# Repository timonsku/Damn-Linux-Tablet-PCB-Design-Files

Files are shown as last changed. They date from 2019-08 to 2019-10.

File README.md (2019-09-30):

DLT - A Damn Linux Tablet
==========
PCB Design Files
-----
Collection of PCB and CAD design files for DLT ( https://hackaday.io/project/164845-dlt-one-a-damn-linux-tablet ).
This project is currently in its early stages and none of the files hosted here are necessarily fully tested, they might work but only to the extent I need them to, some features that I have not tried might not work.
I uploaded them anyway at this stage for documentation purposes and for those that are curious.

All works are licensed under CC BY-SA 4.0.

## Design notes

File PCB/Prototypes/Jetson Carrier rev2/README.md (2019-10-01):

WORK IN PROGRESS
======
This is based of the first revision though some things are not working as expected at the moment so please do not produce any of these boards or base your own boards off this revision, they are here for documentation only!

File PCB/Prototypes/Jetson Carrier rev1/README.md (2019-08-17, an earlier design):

Be aware this a prototype!
====

This means there might be issues with this board.
All peripherals have been tested and are working on this revision, it is mostly based on AntMicros schematics of their open source carrier design.
Still, you might find something not working for you, no gurantees so proceed with caution.

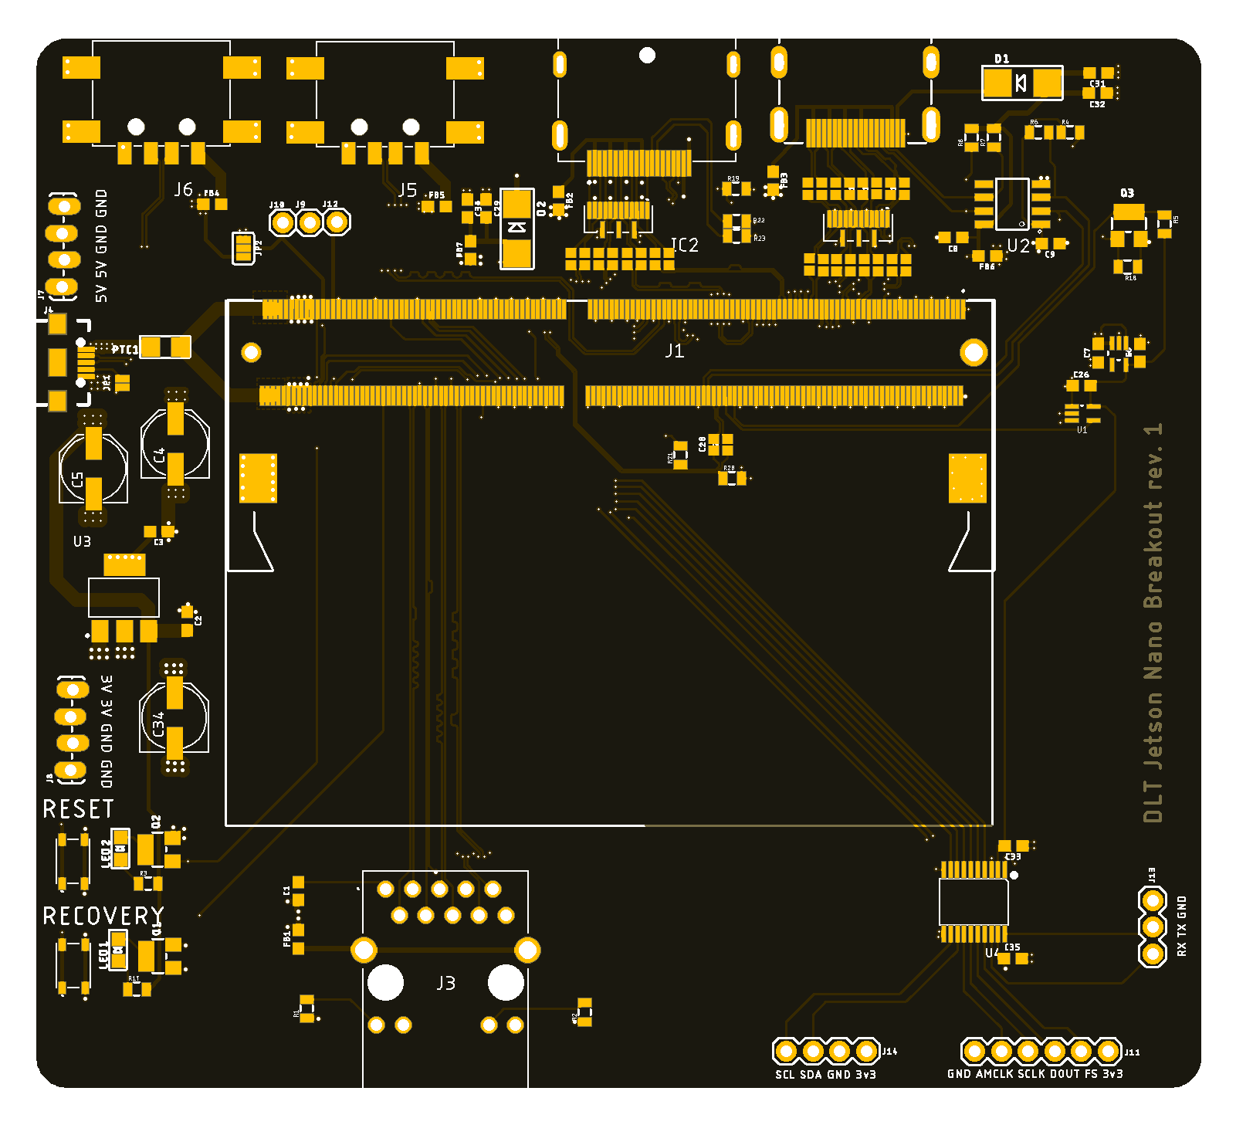
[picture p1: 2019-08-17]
PCB/Prototypes/Jetson Carrier rev2/DLT_Jetson_Nano.png

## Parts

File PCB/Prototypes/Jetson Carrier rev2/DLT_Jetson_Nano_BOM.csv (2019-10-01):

Part | Value | Device | Package | Description | AVAILABILITY | DESCRIPTION | HEIGHT | MANUFACTURER_NAME | MANUFACTURER_PART_NUMBER | MF | MOUSER_PART_NUMBER | MOUSER_PRICE-STOCK | MP | PACKAGE | PRICE | PROD_ID | VALUE
C2 | 1uF | 10NF-0603-50V-10% | 0603 | 0.01uF/10nF/10,000pF ceramic capacitors |  |  |  |  |  |  |  |  |  |  |  | CAP-00867 | 10nF
C3 | 4.7uF | 10NF-0603-50V-10% | 0603 | 0.01uF/10nF/10,000pF ceramic capacitors |  |  |  |  |  |  |  |  |  |  |  | CAP-00867 | 10nF
C4 | 47uF | 47UF-POLAR-EIA3528-10V-10% | EIA3528 | 47µF polarized capacitors |  |  |  |  |  |  |  |  |  |  |  | CAP-08310 | 47uF
C5 | 47uF | 47UF-POLAR-EIA3528-10V-10% | EIA3528 | 47µF polarized capacitors |  |  |  |  |  |  |  |  |  |  |  | CAP-08310 | 47uF
C6 | 1uF | 10NF-0603-50V-10% | 0603 | 0.01uF/10nF/10,000pF ceramic capacitors |  |  |  |  |  |  |  |  |  |  |  | CAP-00867 | 10nF
C7 | 4.7uF | 10NF-0603-50V-10% | 0603 | 0.01uF/10nF/10,000pF ceramic capacitors |  |  |  |  |  |  |  |  |  |  |  | CAP-00867 | 10nF
C10 | 0.1uF | 0.1UF-0402-16V-10% | 0402 | 0.1µF ceramic capacitors |  |  |  |  |  |  |  |  |  |  |  | CAP-12416 | 0.1uF
C11 | 0.1uF | 0.1UF-0402-16V-10% | 0402 | 0.1µF ceramic capacitors |  |  |  |  |  |  |  |  |  |  |  | CAP-12416 | 0.1uF
C12 | 0.1uF | 0.1UF-0402-16V-10% | 0402 | 0.1µF ceramic capacitors |  |  |  |  |  |  |  |  |  |  |  | CAP-12416 | 0.1uF
C13 | 0.1uF | 0.1UF-0402-16V-10% | 0402 | 0.1µF ceramic capacitors |  |  |  |  |  |  |  |  |  |  |  | CAP-12416 | 0.1uF
C14 | 0.1uF | 0.1UF-0402-16V-10% | 0402 | 0.1µF ceramic capacitors |  |  |  |  |  |  |  |  |  |  |  | CAP-12416 | 0.1uF
C15 | 0.1uF | 0.1UF-0402-16V-10% | 0402 | 0.1µF ceramic capacitors |  |  |  |  |  |  |  |  |  |  |  | CAP-12416 | 0.1uF
C16 | 0.1uF | 0.1UF-0402-16V-10% | 0402 | 0.1µF ceramic capacitors |  |  |  |  |  |  |  |  |  |  |  | CAP-12416 | 0.1uF
C17 | 0.1uF | 0.1UF-0402-16V-10% | 0402 | 0.1µF ceramic capacitors |  |  |  |  |  |  |  |  |  |  |  | CAP-12416 | 0.1uF
C18 | 0.1uF | 0.1UF-0402-16V-10% | 0402 | 0.1µF ceramic capacitors |  |  |  |  |  |  |  |  |  |  |  | CAP-12416 | 0.1uF
C19 | 0.1uF | 0.1UF-0402-16V-10% | 0402 | 0.1µF ceramic capacitors |  |  |  |  |  |  |  |  |  |  |  | CAP-12416 | 0.1uF
C20 | 0.1uF | 0.1UF-0402-16V-10% | 0402 | 0.1µF ceramic capacitors |  |  |  |  |  |  |  |  |  |  |  | CAP-12416 | 0.1uF
C21 | 0.1uF | 0.1UF-0402-16V-10% | 0402 | 0.1µF ceramic capacitors |  |  |  |  |  |  |  |  |  |  |  | CAP-12416 | 0.1uF
C22 | 0.1uF | 0.1UF-0402-16V-10% | 0402 | 0.1µF ceramic capacitors |  |  |  |  |  |  |  |  |  |  |  | CAP-12416 | 0.1uF
C23 | 0.1uF | 0.1UF-0402-16V-10% | 0402 | 0.1µF ceramic capacitors |  |  |  |  |  |  |  |  |  |  |  | CAP-12416 | 0.1uF
C24 | 0.1uF | 0.1UF-0402-16V-10% | 0402 | 0.1µF ceramic capacitors |  |  |  |  |  |  |  |  |  |  |  | CAP-12416 | 0.1uF
C25 | 0.1uF | 0.1UF-0402-16V-10% | 0402 | 0.1µF ceramic capacitors |  |  |  |  |  |  |  |  |  |  |  | CAP-12416 | 0.1uF
C27 | 0.1uF | 0.1UF-0402-16V-10% | 0402 | 0.1µF ceramic capacitors |  |  |  |  |  |  |  |  |  |  |  | CAP-12416 | 0.1uF
C28 | 0.1uF | 0.1UF-0402-16V-10% | 0402 | 0.1µF ceramic capacitors |  |  |  |  |  |  |  |  |  |  |  | CAP-12416 | 0.1uF
C29 | 4.7uF | 10NF-0603-50V-10% | 0603 | 0.01uF/10nF/10,000pF ceramic capacitors |  |  |  |  |  |  |  |  |  |  |  | CAP-00867 | 10nF
C30 | 4.7uF | 10NF-0603-50V-10% | 0603 | 0.01uF/10nF/10,000pF ceramic capacitors |  |  |  |  |  |  |  |  |  |  |  | CAP-00867 | 10nF
C31 | 4.7uF | 10NF-0603-50V-10% | 0603 | 0.01uF/10nF/10,000pF ceramic capacitors |  |  |  |  |  |  |  |  |  |  |  | CAP-00867 | 10nF
C32 | 4.7uF | 10NF-0603-50V-10% | 0603 | 0.01uF/10nF/10,000pF ceramic capacitors |  |  |  |  |  |  |  |  |  |  |  | CAP-00867 | 10nF
C34 | 47uF | 47UF-POLAR-EIA3528-10V-10% | EIA3528 | 47µF polarized capacitors |  |  |  |  |  |  |  |  |  |  |  | CAP-08310 | 47uF
CN1 |  | JST_2PIN-SMT-RA | JST-PH-2-SMT-RA | JST 2-Pin Connectors of various flavors
CN2 |  | JST_2PIN-SMT-RA | JST-PH-2-SMT-RA | JST 2-Pin Connectors of various flavors
FB2 | .25/3A | FERRITE_BEAD-0603 | 0603 | Ferrite Bead (blocks, cores, rings, chokes, etc.) |  |  |  |  |  |  |  |  |  |  |  | NDUC-13805 | 30Ω/1.8A
FB3 | .25/3A | FERRITE_BEAD-0603 | 0603 | Ferrite Bead (blocks, cores, rings, chokes, etc.) |  |  |  |  |  |  |  |  |  |  |  | NDUC-13805 | 30Ω/1.8A
FB6 | .25/3A | FERRITE_BEAD-0603 | 0603 | Ferrite Bead (blocks, cores, rings, chokes, etc.) |  |  |  |  |  |  |  |  |  |  |  | NDUC-13805 | 30Ω/1.8A
FB7 | .25/3A | FERRITE_BEAD-0603 | 0603 | Ferrite Bead (blocks, cores, rings, chokes, etc.) |  |  |  |  |  |  |  |  |  |  |  | NDUC-13805 | 30Ω/1.8A
IC1 | TPD8S009DSMR | TPD8S009DSMR | TPD8S009DSMR | 8-Channel ESD Solution for HDMI/DisplayPort |  | 8-Channel ESD Solution for HDMI/DisplayPort | 0mm | Texas Instruments | TPD8S009DSMR |  | 595-TPD8S009DSMR | https://www.mouser.com/Search/Refine.aspx?Keyword=595-TPD8S009DSMR
IC2 | TPD8S009DSMR | TPD8S009DSMR | TPD8S009DSMR | 8-Channel ESD Solution for HDMI/DisplayPort |  | 8-Channel ESD Solution for HDMI/DisplayPort | 0mm | Texas Instruments | TPD8S009DSMR |  | 595-TPD8S009DSMR | https://www.mouser.com/Search/Refine.aspx?Keyword=595-TPD8S009DSMR
IC3 | TLV70018DCKR | TLV70018DCKR | SOT65P210X110-5N | 200-mA, Low-IQ, Low-Dropout Regulator for Portable Devices |  | 200-mA, Low-IQ, Low-Dropout Regulator for Portable Devices | mm | Texas Instruments | TLV70018DCKR |  | 595-TLV70018DCKR | https://www.mouser.com/Search/Refine.aspx?Keyword=595-TLV70018DCKR
J1 | 2309409-1 | 2309409-1 | 2309409-1 | TE CONNECTIVITY - 2309409-1 - CONN, DDR4 SODIMM SOCKET, 260POS, 0.5MM |  | TE CONNECTIVITY - 2309409-1 - CONN, DDR4 SODIMM SOCKET, 260POS, 0.5MM | mm | TE Connectivity | 2309409-1 |  | 571-2309409-1 | https://www.mouser.com/Search/Refine.aspx?Keyword=571-2309409-1
J2 | 54132-3062 | 54132-3062 | 54132-3062 | Connector 0.5mm, FFC/FPC, SMT,r/a,30w,Au Molex FFC/FPC SMT Series 0.5mm Pitch 30 Way Right Angle SMT Female FPC Connector, ZIF Bottom Contact |  | Connector 0.5mm, FFC/FPC, SMT,r/a,30w,Au Molex FFC/FPC SMT Series 0.5mm Pitch 30 Way Right Angle SMT Female FPC Connector, ZIF Bottom Contact | mm | Molex | 54132-3062 |  | 538-54132-3062 | https://www.mouser.com/Search/Refine.aspx?Keyword=538-54132-3062
J3 | 505110-1092 | 505110-1092 | 5051101092 | Molex Easy-On Series 0.5mm Pitch 10 Way Right Angle SMT Male FPC Connector, ZIF Bottom Contact |  | Molex Easy-On Series 0.5mm Pitch 10 Way Right Angle SMT Male FPC Connector, ZIF Bottom Contact | 0mm | Molex | 505110-1092 |  | 538-505110-1092 | https://www.mouser.com/Search/Refine.aspx?Keyword=538-505110-1092
J4 | 505110-1092 | 505110-1092 | 5051101092 | Molex Easy-On Series 0.5mm Pitch 10 Way Right Angle SMT Male FPC Connector, ZIF Bottom Contact |  | Molex Easy-On Series 0.5mm Pitch 10 Way Right Angle SMT Male FPC Connector, ZIF Bottom Contact | 0mm | Molex | 505110-1092 |  | 538-505110-1092 | https://www.mouser.com/Search/Refine.aspx?Keyword=538-505110-1092
J5 | 505110-1092 | 505110-1092 | 5051101092 | Molex Easy-On Series 0.5mm Pitch 10 Way Right Angle SMT Male FPC Connector, ZIF Bottom Contact |  | Molex Easy-On Series 0.5mm Pitch 10 Way Right Angle SMT Male FPC Connector, ZIF Bottom Contact | 0mm | Molex | 505110-1092 |  | 538-505110-1092 | https://www.mouser.com/Search/Refine.aspx?Keyword=538-505110-1092
J6 |  | CONN_01 | 1X01 | Single connection point. Often used as Generic Header-pin footprint for 0.1 inch spaced/style header connections
J7 | 505110-2091 | 505110-2091 | 5051102091 | MOLEX - 505110-2091 - CONNECTOR, FFC/FPC, 20POS, 1ROW, 0.5MM |  | MOLEX - 505110-2091 - CONNECTOR, FFC/FPC, 20POS, 1ROW, 0.5MM | 2.1mm | Molex | 505110-2091 |  | 538-505110-2091 | https://www.mouser.com/Search/Refine.aspx?Keyword=538-505110-2091
J8 |  | CONN_01 | 1X01 | Single connection point. Often used as Generic Header-pin footprint for 0.1 inch spaced/style header connections
J9 |  | CONN_01 | 1X01 | Single connection point. Often used as Generic Header-pin footprint for 0.1 inch spaced/style header connections
J10 | 505110-2091 | 505110-2091 | 5051102091 | MOLEX - 505110-2091 - CONNECTOR, FFC/FPC, 20POS, 1ROW, 0.5MM |  | MOLEX - 505110-2091 - CONNECTOR, FFC/FPC, 20POS, 1ROW, 0.5MM | 2.1mm | Molex | 505110-2091 |  | 538-505110-2091 | https://www.mouser.com/Search/Refine.aspx?Keyword=538-505110-2091
J11 |  | CONN_01 | 1X01 | Single connection point. Often used as Generic Header-pin footprint for 0.1 inch spaced/style header connections
J12 |  | CONN_01 | 1X01 | Single connection point. Often used as Generic Header-pin footprint for 0.1 inch spaced/style header connections
J13 |  | CONN_01 | 1X01 | Single connection point. Often used as Generic Header-pin footprint for 0.1 inch spaced/style header connections
J15 | 54132-3062 | 54132-3062 | 54132-3062 | Connector 0.5mm, FFC/FPC, SMT,r/a,30w,Au Molex FFC/FPC SMT Series 0.5mm Pitch 30 Way Right Angle SMT Female FPC Connector, ZIF Bottom Contact |  | Connector 0.5mm, FFC/FPC, SMT,r/a,30w,Au Molex FFC/FPC SMT Series 0.5mm Pitch 30 Way Right Angle SMT Female FPC Connector, ZIF Bottom Contact | mm | Molex | 54132-3062 |  | 538-54132-3062 | https://www.mouser.com/Search/Refine.aspx?Keyword=538-54132-3062
JP2 | JUMPER-SMT_3_1-NC_TRACE_NO-SILK | JUMPER-SMT_3_1-NC_TRACE_NO-SILK | SMT-JUMPER_3_1-NC_TRACE_NO-SILK | Normally closed trace jumper (1 of 2 connections)
LOGO1 | OSHW-LOGOS-COPPER | OSHW-LOGOS-COPPER | OSHW-LOGO-S_COPPER | Open-Source Hardware (OSHW) Logo
ON |  | LED0805 | CHIPLED_0805 | LED
PTC1 |  | PTC1206 | 1206 | PTC (Resettable Fuse)
PTC2 |  | PTC1206 | 1206 | PTC (Resettable Fuse)
PTC3 |  | PTC1206 | 1206 | PTC (Resettable Fuse)
PTC4 |  | PTC1206 | 1206 | PTC (Resettable Fuse)
PWR |  | LED0805 | CHIPLED_0805 | LED
Q2 |  | MOSFET-NWAVE | SOT23-W | N-Channel Mosfet
R3 |  | RESISTOR0805-RES | 0805 | Resistor
R17 |  | RESISTOR0805-RES | 0805 | Resistor
R20 | 100k | RESISTOR0805-RES | 0805 | Resistor
R21 | 100k | RESISTOR0805-RES | 0805 | Resistor
S2 | SKRPADE010 | SKRPADE010 | SKRPADE010 | Tactile Switches 4.2x3.2x2.5mm 408gf |  | Tactile Switches 4.2x3.2x2.5mm 408gf | 2mm | ALPS | SKRPADE010 |  | 688-SKRPAD | https://www.mouser.com/Search/Refine.aspx?Keyword=688-SKRPAD
S4 | SKRPADE010 | SKRPADE010 | SKRPADE010 | Tactile Switches 4.2x3.2x2.5mm 408gf |  | Tactile Switches 4.2x3.2x2.5mm 408gf | 2mm | ALPS | SKRPADE010 |  | 688-SKRPAD | https://www.mouser.com/Search/Refine.aspx?Keyword=688-SKRPAD
U3 | LDL1117S12R | LDL1117S12R | SOT230P700X180-4N | None | Good | 1.2 A High PSRR low dropout linear voltage regulator |  |  |  | STMicroelectronics |  |  | LDL1117S12R | SOT-223 STMicroelectronics | 0.22 USD

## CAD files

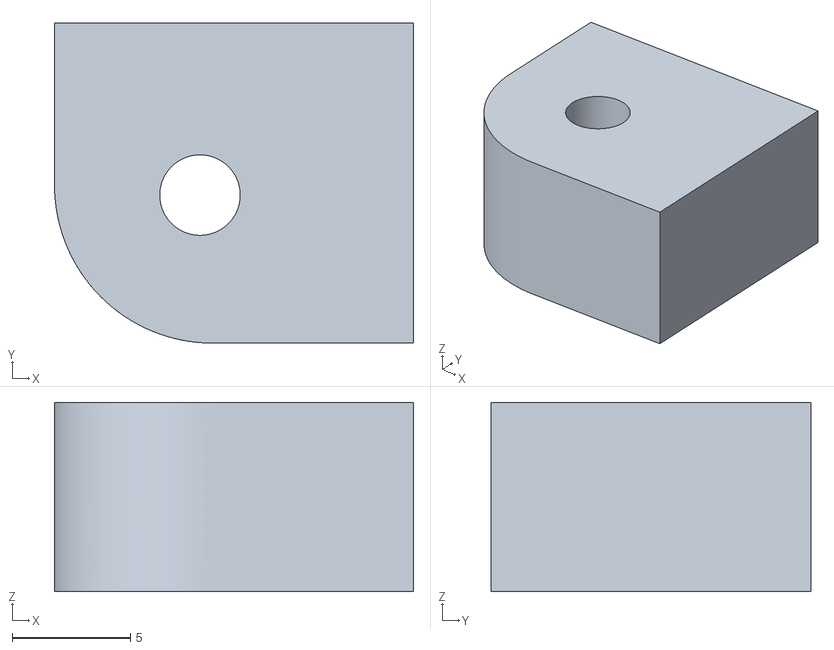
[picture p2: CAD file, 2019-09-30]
Mechanical/Mechanical Prototype rev. 1/Corner Bottom Left.stl
15.2 x 13.5 x 8.00

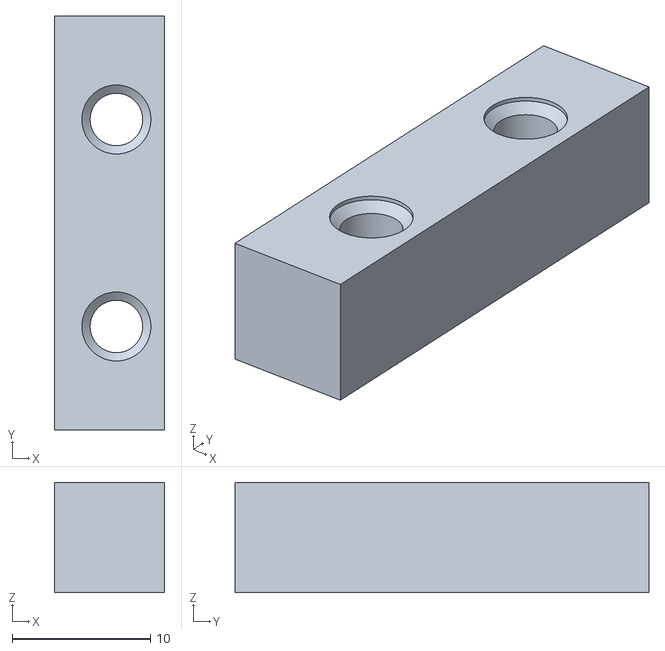
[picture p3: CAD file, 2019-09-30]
Mechanical/Mechanical Prototype rev. 1/Spacer Block 40mm.stl
8.00 x 30.0 x 8.00

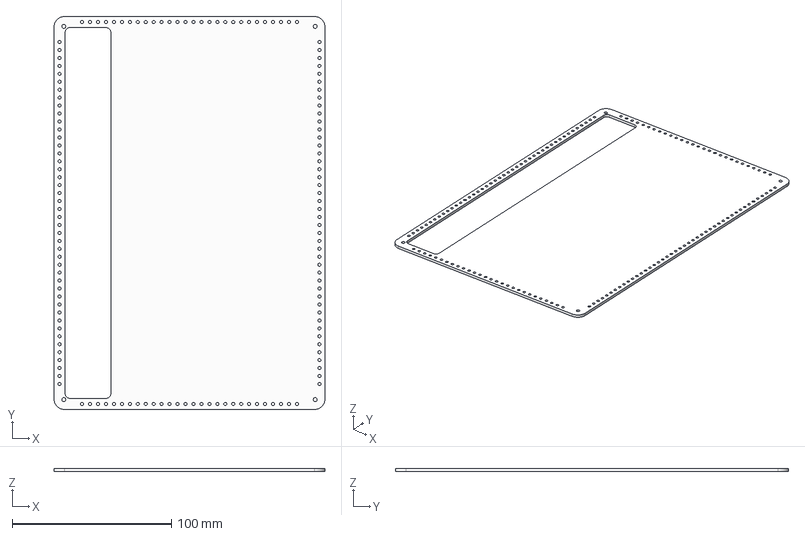
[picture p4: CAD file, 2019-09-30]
Mechanical/Mechanical Prototype rev. 1/Mounting Plate.step
170.4 x 247.1 x 2.00 mm

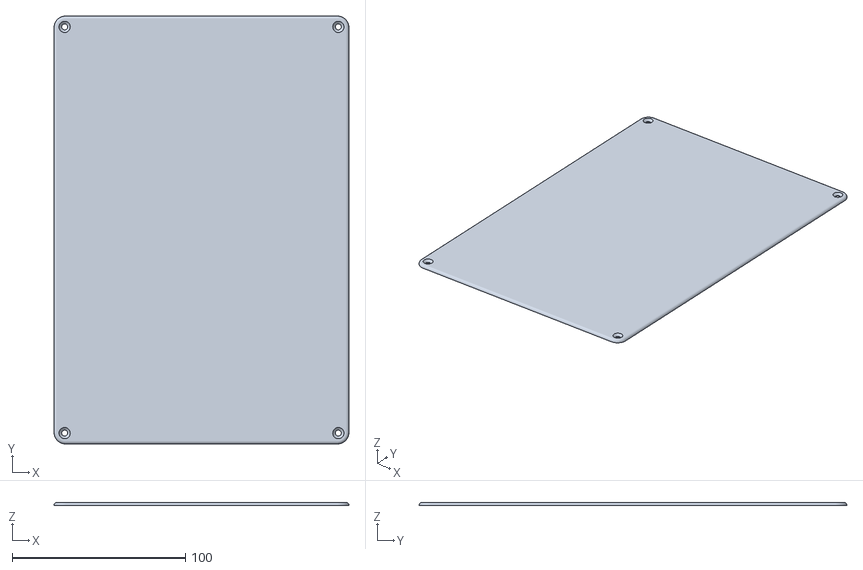
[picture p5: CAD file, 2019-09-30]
Mechanical/Mechanical Prototype rev. 1/Back Plate.stl
170.4 x 247.1 x 2.00

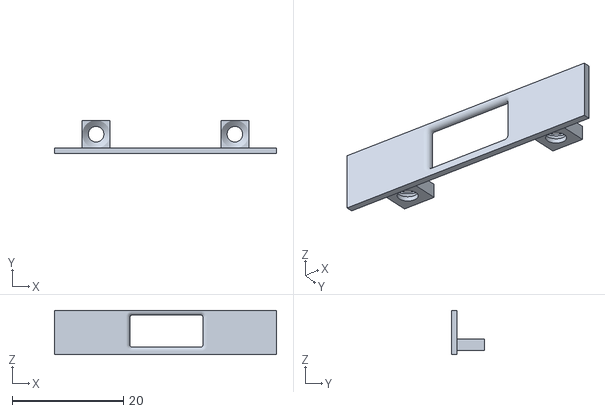
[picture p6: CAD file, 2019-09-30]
Mechanical/Mechanical Prototype rev. 1/USB-A Faceplate.stl
40.0 x 6.00 x 8.00

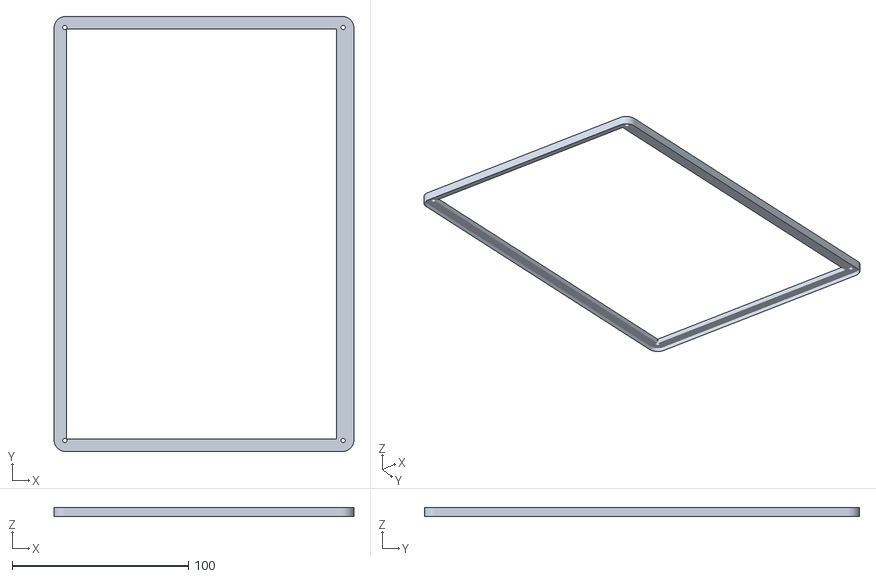
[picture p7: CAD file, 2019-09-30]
Mechanical/Mechanical Prototype rev. 1/Display Frame.stl
170.4 x 247.1 x 5.20

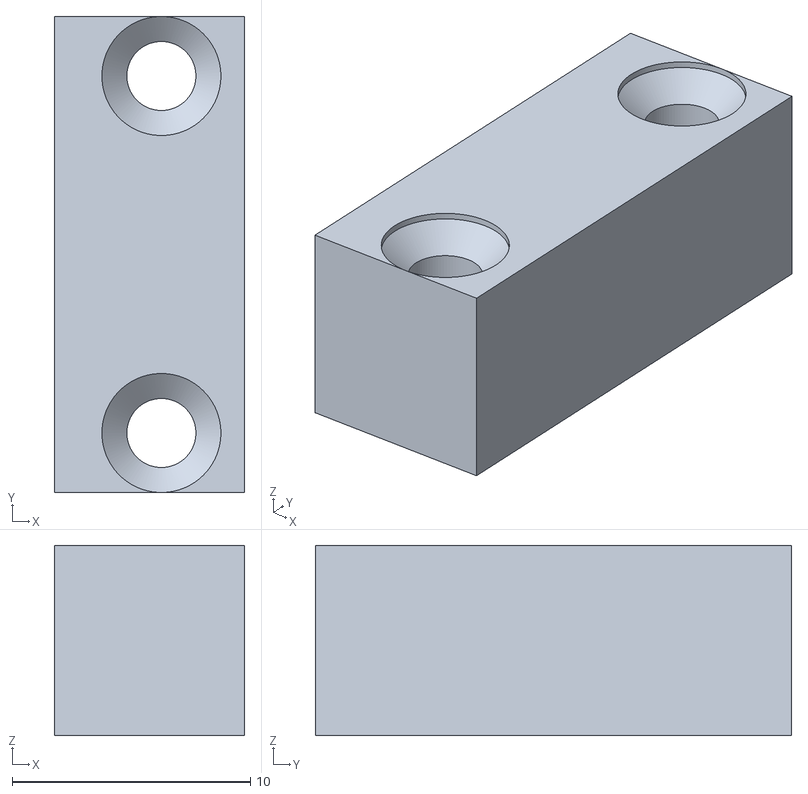
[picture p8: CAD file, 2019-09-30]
Mechanical/Mechanical Prototype rev. 1/Spacer Block 20mm.stl
8.00 x 20.0 x 8.00

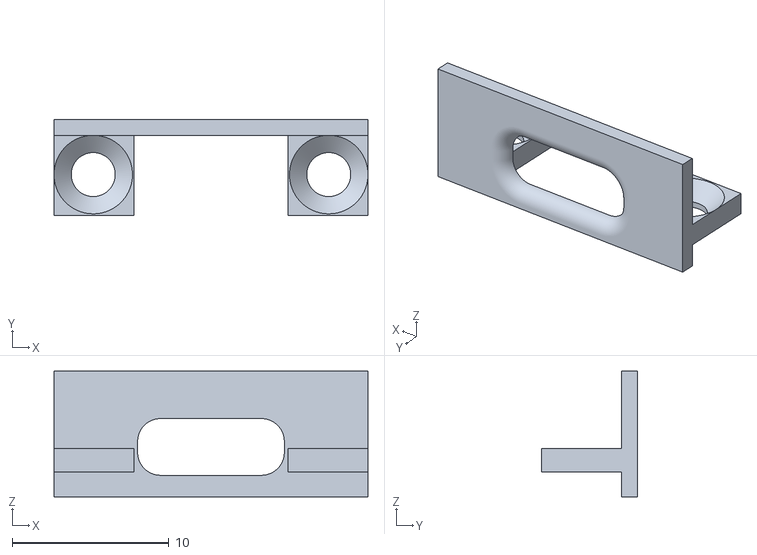
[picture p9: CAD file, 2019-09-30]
Mechanical/Mechanical Prototype rev. 1/USB-C Faceplate.stl
20.0 x 6.10 x 8.00

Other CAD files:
Mechanical/Mechanical Prototype rev. 1/Corner Bottom Right.stl
Mechanical/Mechanical Prototype rev. 1/Corner Top Left.stl
Mechanical/Mechanical Prototype rev. 1/Corner Top Right.stl
Mechanical/Mechanical Prototype rev. 1/DLT-10inch-Assembly v29.f3z
Mechanical/Mechanical Prototype rev. 1/Mounting Plate.stl
Mechanical/Mechanical Prototype rev. 1/backplate.dxf

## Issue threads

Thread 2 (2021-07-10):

DLT v2 ?

Azkali, 2021-07-10:
Hi, first of all I wanted to let you know that I followed your work on this DLT and Pi CM4 carrier board and all I can say is thank you for such great work and keeping your sources open !

I am currently working on a few software projects surrounding Jetson platforms ( Jetson Nano, Xavier NX, TX1 ).
And I'd be very interested with the help of our contributors to pursue your work on this DLT.

But I think it would be best to share you an [invitation to our Discord](https://discord.gg/53mtKYt) to discuss this further if you happen to have any time for us.

timonsku, 2021-07-10:
Hi Azkali,
I somewhat shelved the project atm as I concentrated on some other products. I do plan to continue working on it but might go into a bit of a different direction. I realized in order to continue at this point I need to work towards commercializing and for that I do need to think a bit more about the potential audience. Focusing a little bit on a gaming direction was definitely part of those thoughts.
Making a device like that commercially is a huge undertaking so I'm currently bootstrapping a bit with smaller products.

I really appreciate the interest and it is nice to see that there is an active community around the Jetson line outside of traditional industry. What did you want to talk about specifically?

cybik, 2021-07-10:
For the record, while I would not be able to help on the development of this thing, if at some point y'all would need early version testers (that would need to pay some non-ridiculous amounts to get the development boards and parts), I may be interested.

Azkali, 2021-07-11:
Thank you for the answer, we are interested to create a similar device and initially wanted to base ourselves on your work, we wanted to have some insights on BMS and are planning to add support for the different M2 sockets as those are the only important feature that seem to be missing for our simple use case. We are mostly doing software and low level development and thouht a Xavier NX based tablet would be helpful for this purpose especially when we have the ability to swap the SoM for TX2 NX / Nano.

timonsku, 2021-07-11:
BMS is by far the most complicated part, at least if you are planning for a real world device. It is one of the reasons why I shelved it at the moment as that will need quite a lot of considerations and gets really complicated when you introduce USB-PD which you most certainly want to support with such a high power SoC. If you make it a charging only port it gets a bit easier but if you also want to support USB3.0 and Dual Role port as you would see on most modern tablets it become a project on its own.

Breaking PCI-e out is pretty trivial of course, that would certainly be part of the next iteration.

Azkali, 2021-07-11:
Yes.. After some thinking we came to this conclusion as well for the BMS. Are you still keeping your sources open even with the commercial plan ? ( I would buy one to support you anyway )

At the moment is there any issue preventing me from using current board revision granted that I have someone produce it ?

Maybe I could always give help breaking out PCI-e so that you have less to do ?

timonsku, 2021-07-11:
Yes the design will always be open source, that would not change. The plan for commercialization was always there but never very concrete.

The current revision has a mistake with the HDMI pinout, the eDP/DP port was working fine it is what I used to test the eDP panel.

When it comes to board layout I don't really need help but thanks :)
The complications are more on a sourcing and system design level. I have some friends who can help me with the BMS side of things but before I put more work into this I need to come up with a more detailed business plan.

A crowdfunding would certainly be coming but that is only really useful once I have a product prototype and know where things are going. You need to price out parts and have suppliers for everything before a crowdfunding can be done otherwise there is a high risk that I loose money.
Right now I'm finishing up Piunora which went through Crowdfunding in April: https://www.crowdsupply.com/diodes-delight/piunora

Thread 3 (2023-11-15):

Modular edge + mounting plate

eklem, 2023-11-15:
Fantastic work! The idea with the mounting plate and modular edge is worth the project alone from my point of view! I'm just going to use OrangePi Zero 2 W and then connect a port or three on the edge.

So, not a real issue opened, but a thank you, and also a little idea that it could be a good design pattern, even if you don't use all the nice hardware you've designed.

timonsku, 2023-11-15:
nice to hear, thank you!
And for sure, the idea always was to build a system "specification". The specific implementation is not really relevant :)
Unfortunately to develop specs you need a reference implementation and it became a bit prohibitive in terms of cost and time to fully flesh it out into a ready to use tablet.
The Hackaday.io project log entries talk a bit more in-depth about some of the proposed concepts.

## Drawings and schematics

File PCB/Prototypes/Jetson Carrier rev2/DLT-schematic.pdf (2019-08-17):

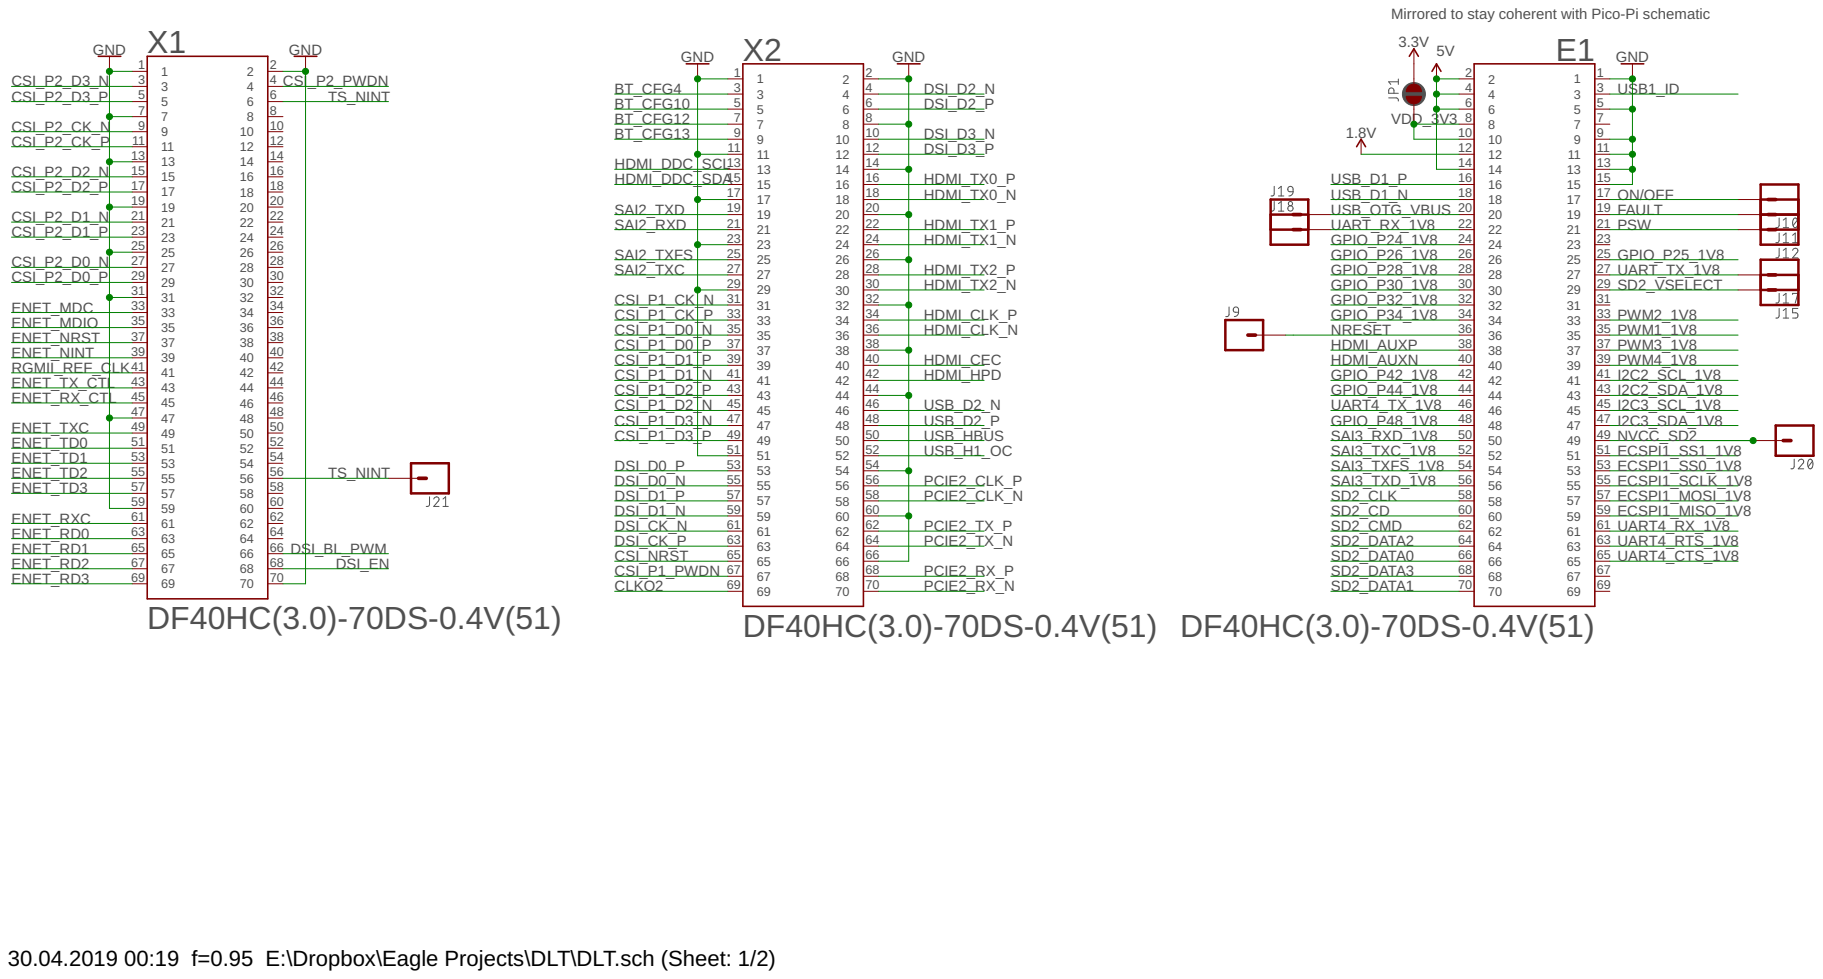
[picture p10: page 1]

Mirrored to stay coherent with Pico-Pi schematic

30.04.2019 00:19 f=0.95 E:\Dropbox\Eagle Projects\DLT\DLT.sch (Sheet: 1/2)

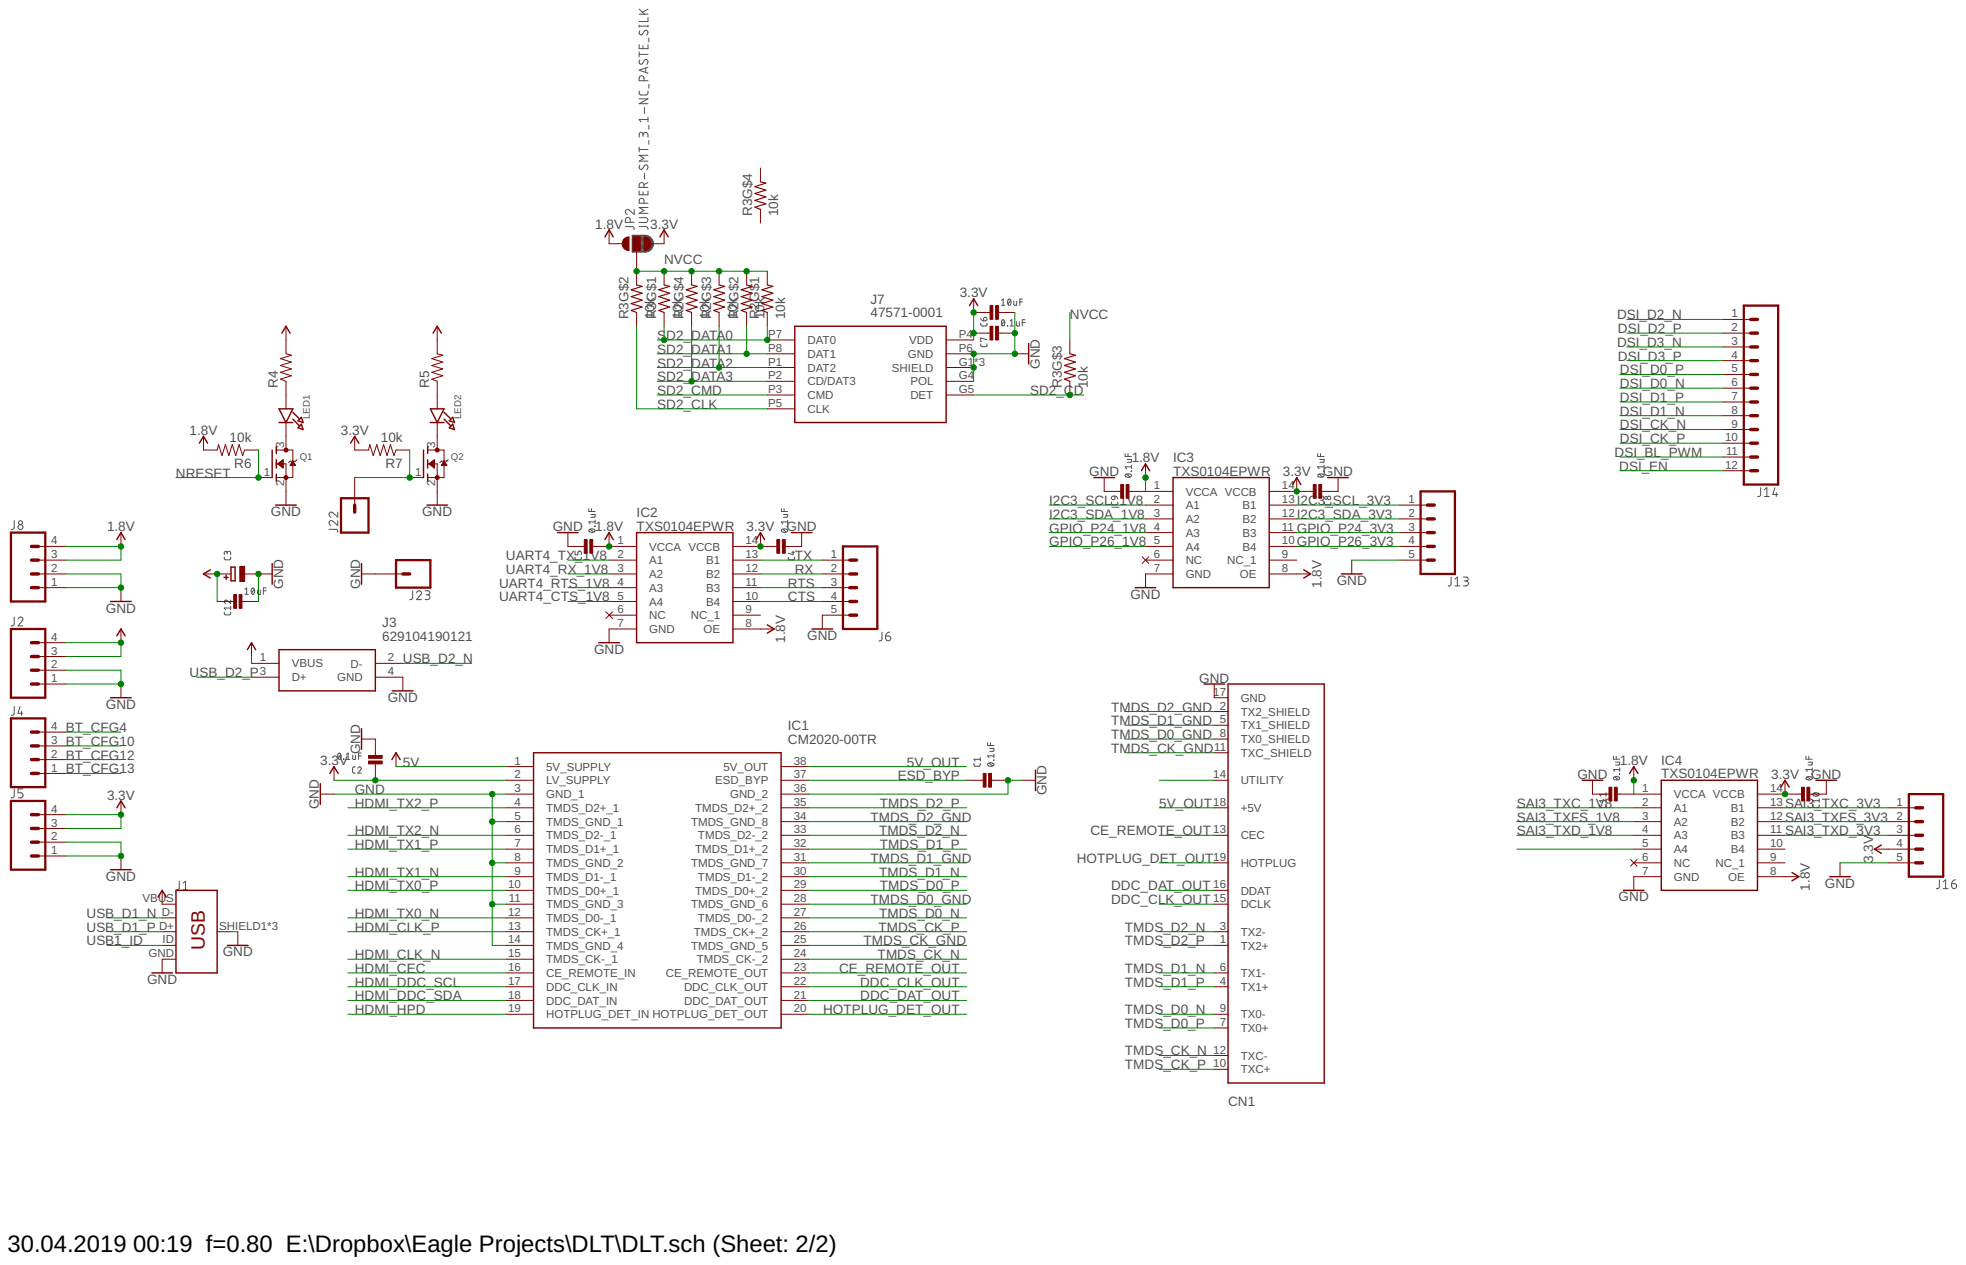
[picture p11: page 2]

30.04.2019 00:19 f=0.80 E:\Dropbox\Eagle Projects\DLT\DLT.sch (Sheet: 2/2)

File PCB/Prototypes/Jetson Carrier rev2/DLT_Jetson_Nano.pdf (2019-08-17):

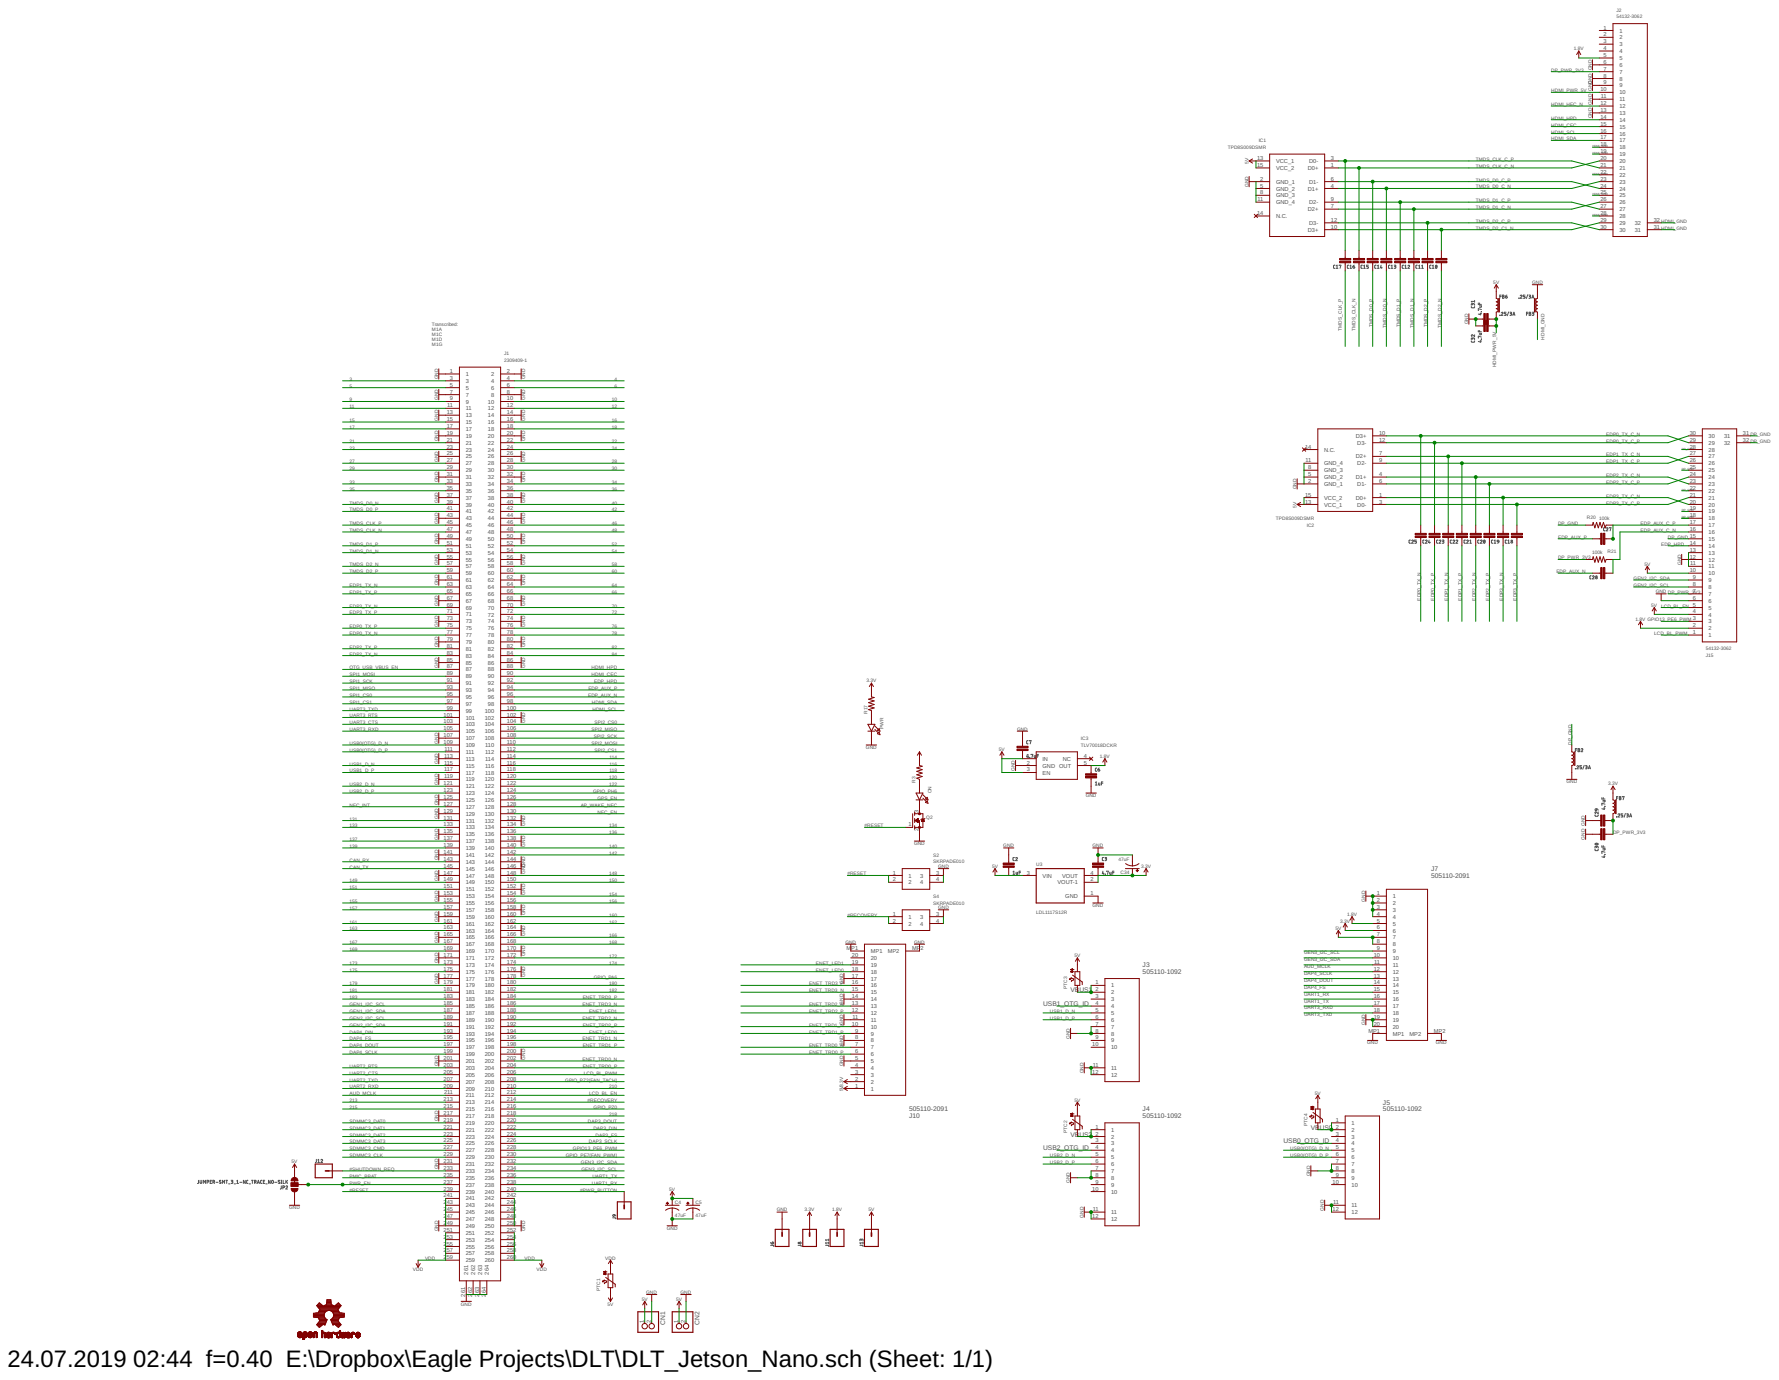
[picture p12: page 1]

GND GND GNDGND GND

GND GND

GND GND GND GND GND 5V3.3V GND GND

24.07.2019 02:44 f=0.40 E:\Dropbox\Eagle Projects\DLT\DLT_Jetson_Nano.sch (Sheet: 1/1)

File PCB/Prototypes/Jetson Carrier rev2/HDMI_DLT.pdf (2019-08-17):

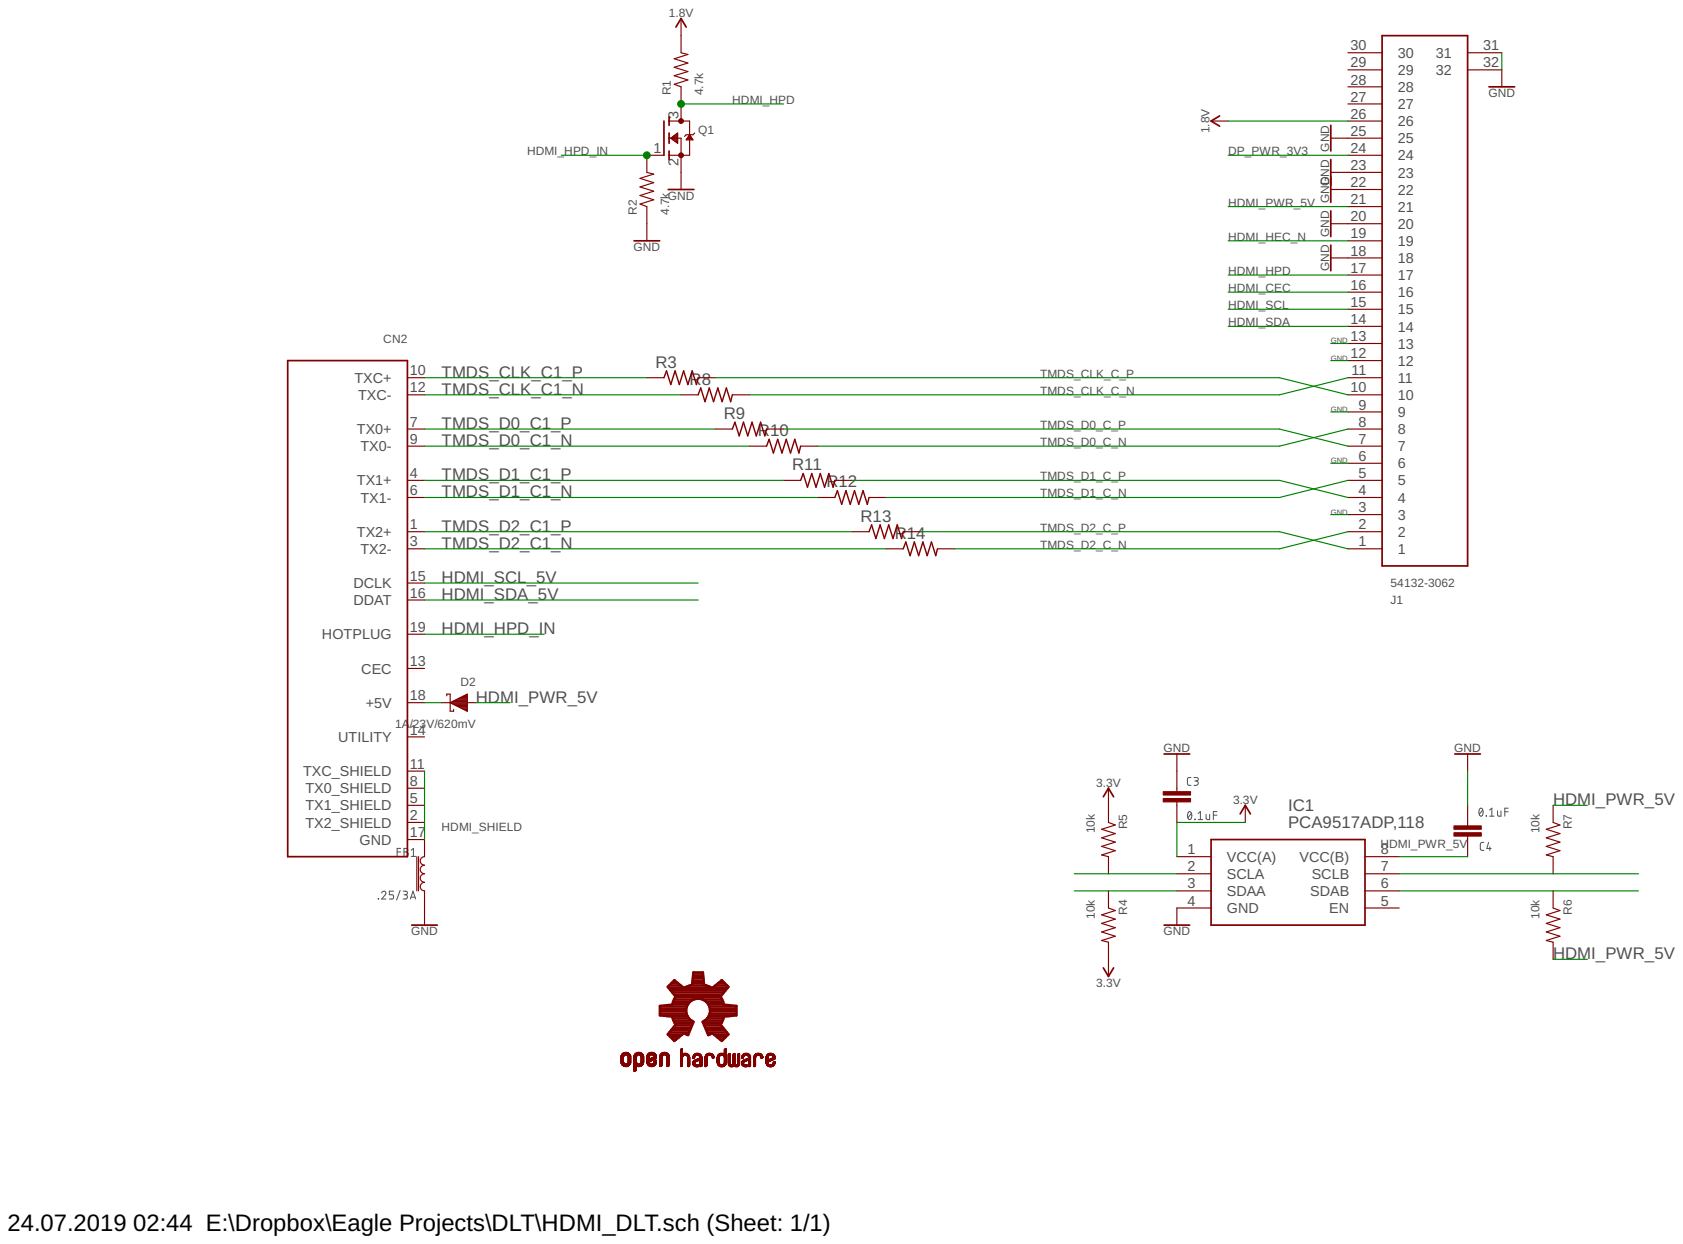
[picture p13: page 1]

GND GND GNDGND GND

24.07.2019 02:44 E:\Dropbox\Eagle Projects\DLT\HDMI_DLT.sch (Sheet: 1/1)

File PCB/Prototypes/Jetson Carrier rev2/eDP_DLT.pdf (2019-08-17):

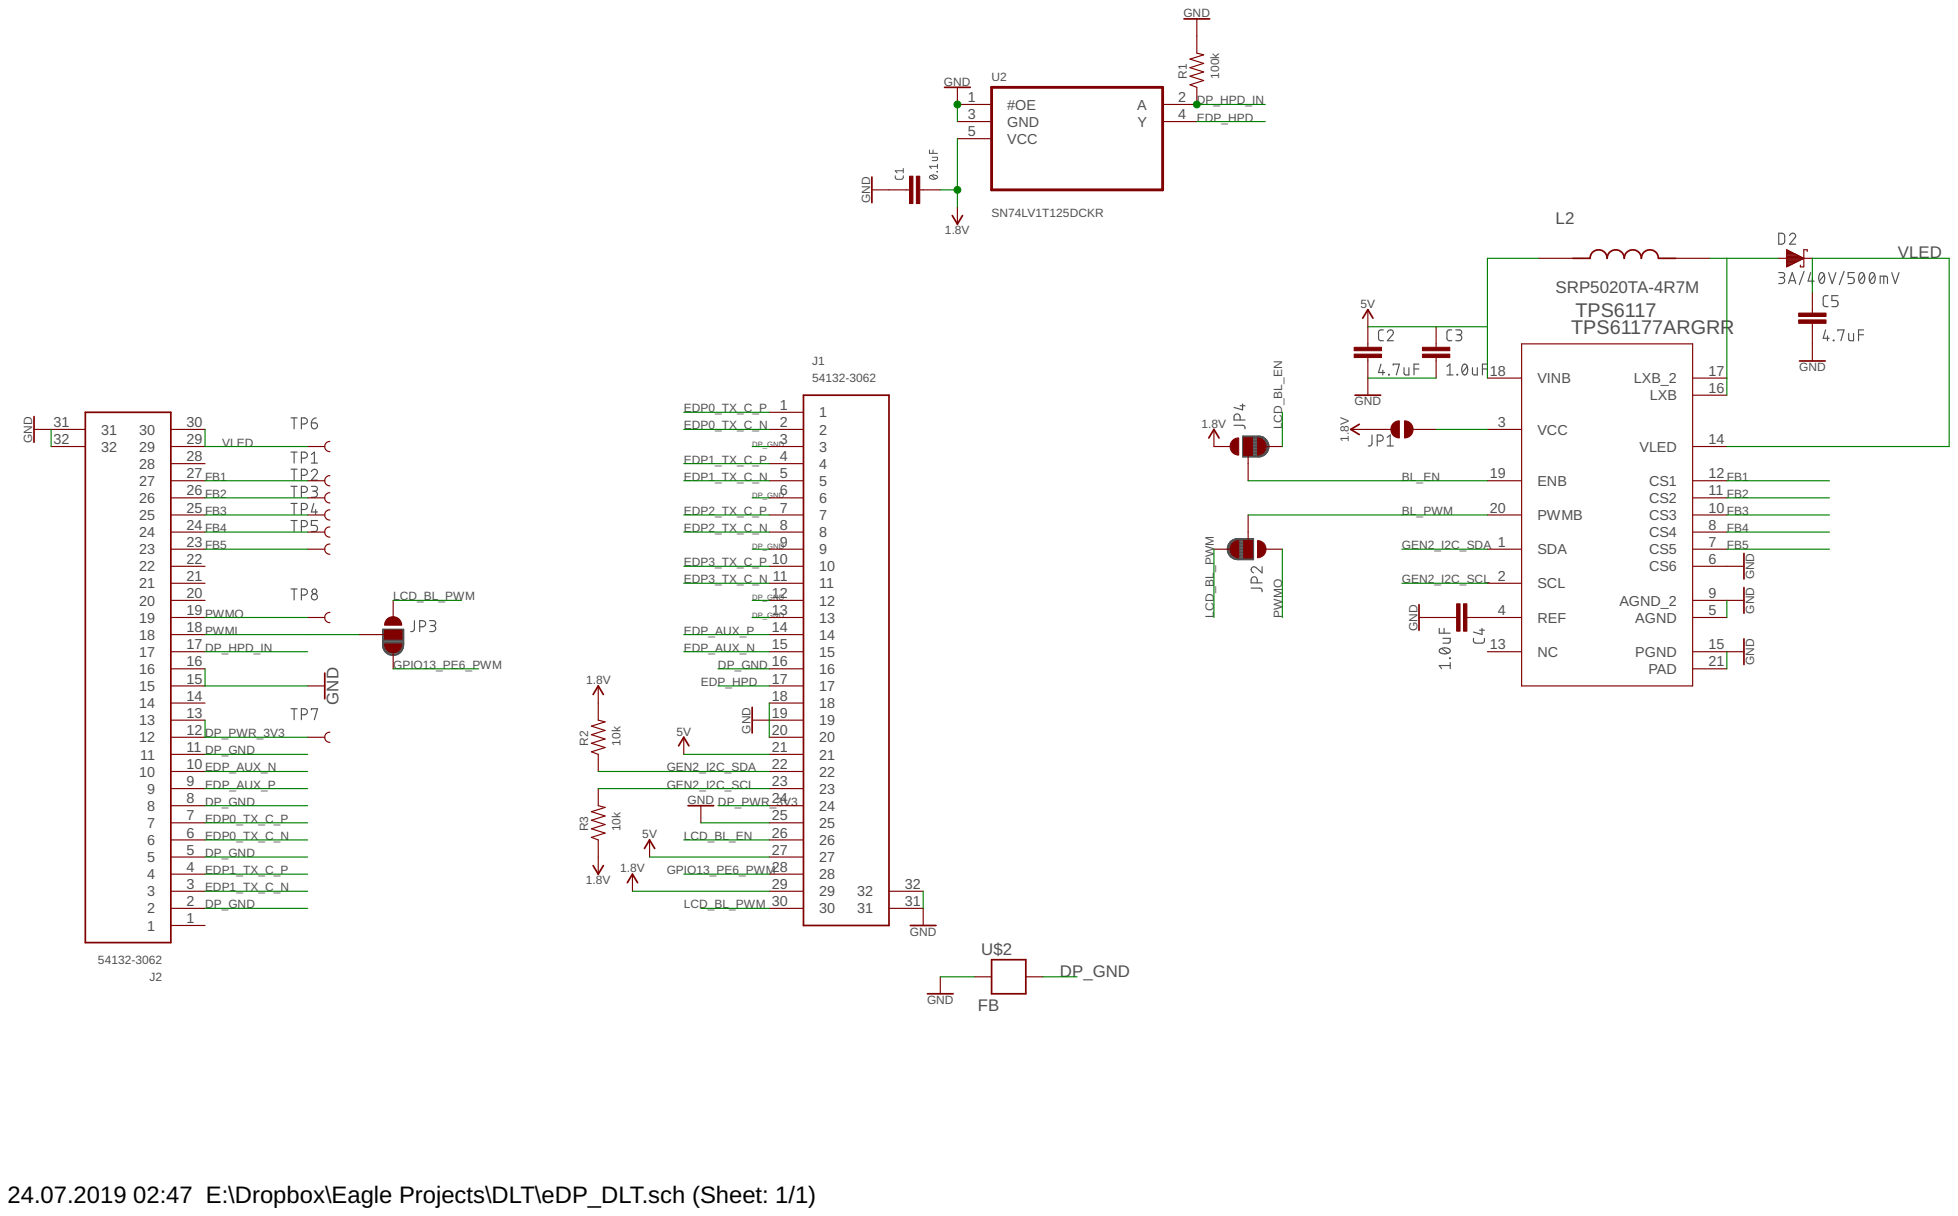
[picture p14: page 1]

24.07.2019 02:47 E:\Dropbox\Eagle Projects\DLT\eDP_DLT.sch (Sheet: 1/1)

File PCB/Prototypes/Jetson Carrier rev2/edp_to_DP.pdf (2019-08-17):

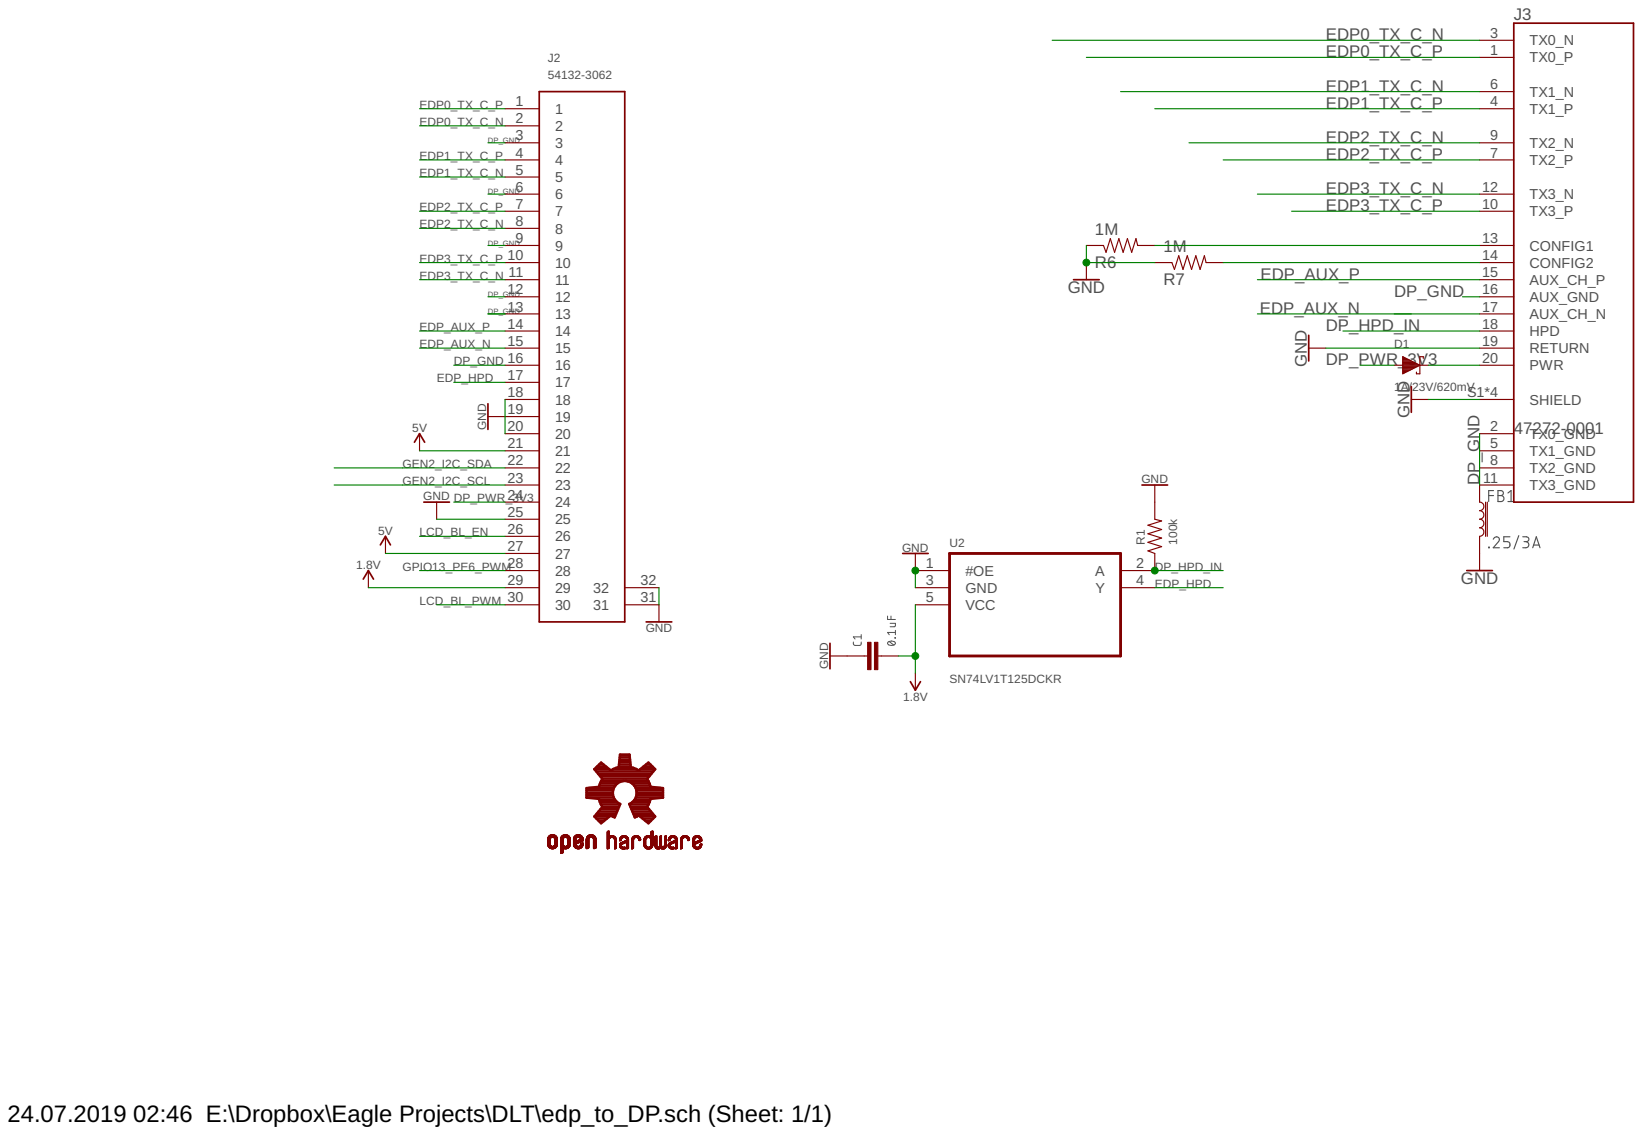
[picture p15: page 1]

24.07.2019 02:46 E:\Dropbox\Eagle Projects\DLT\edp_to_DP.sch (Sheet: 1/1)

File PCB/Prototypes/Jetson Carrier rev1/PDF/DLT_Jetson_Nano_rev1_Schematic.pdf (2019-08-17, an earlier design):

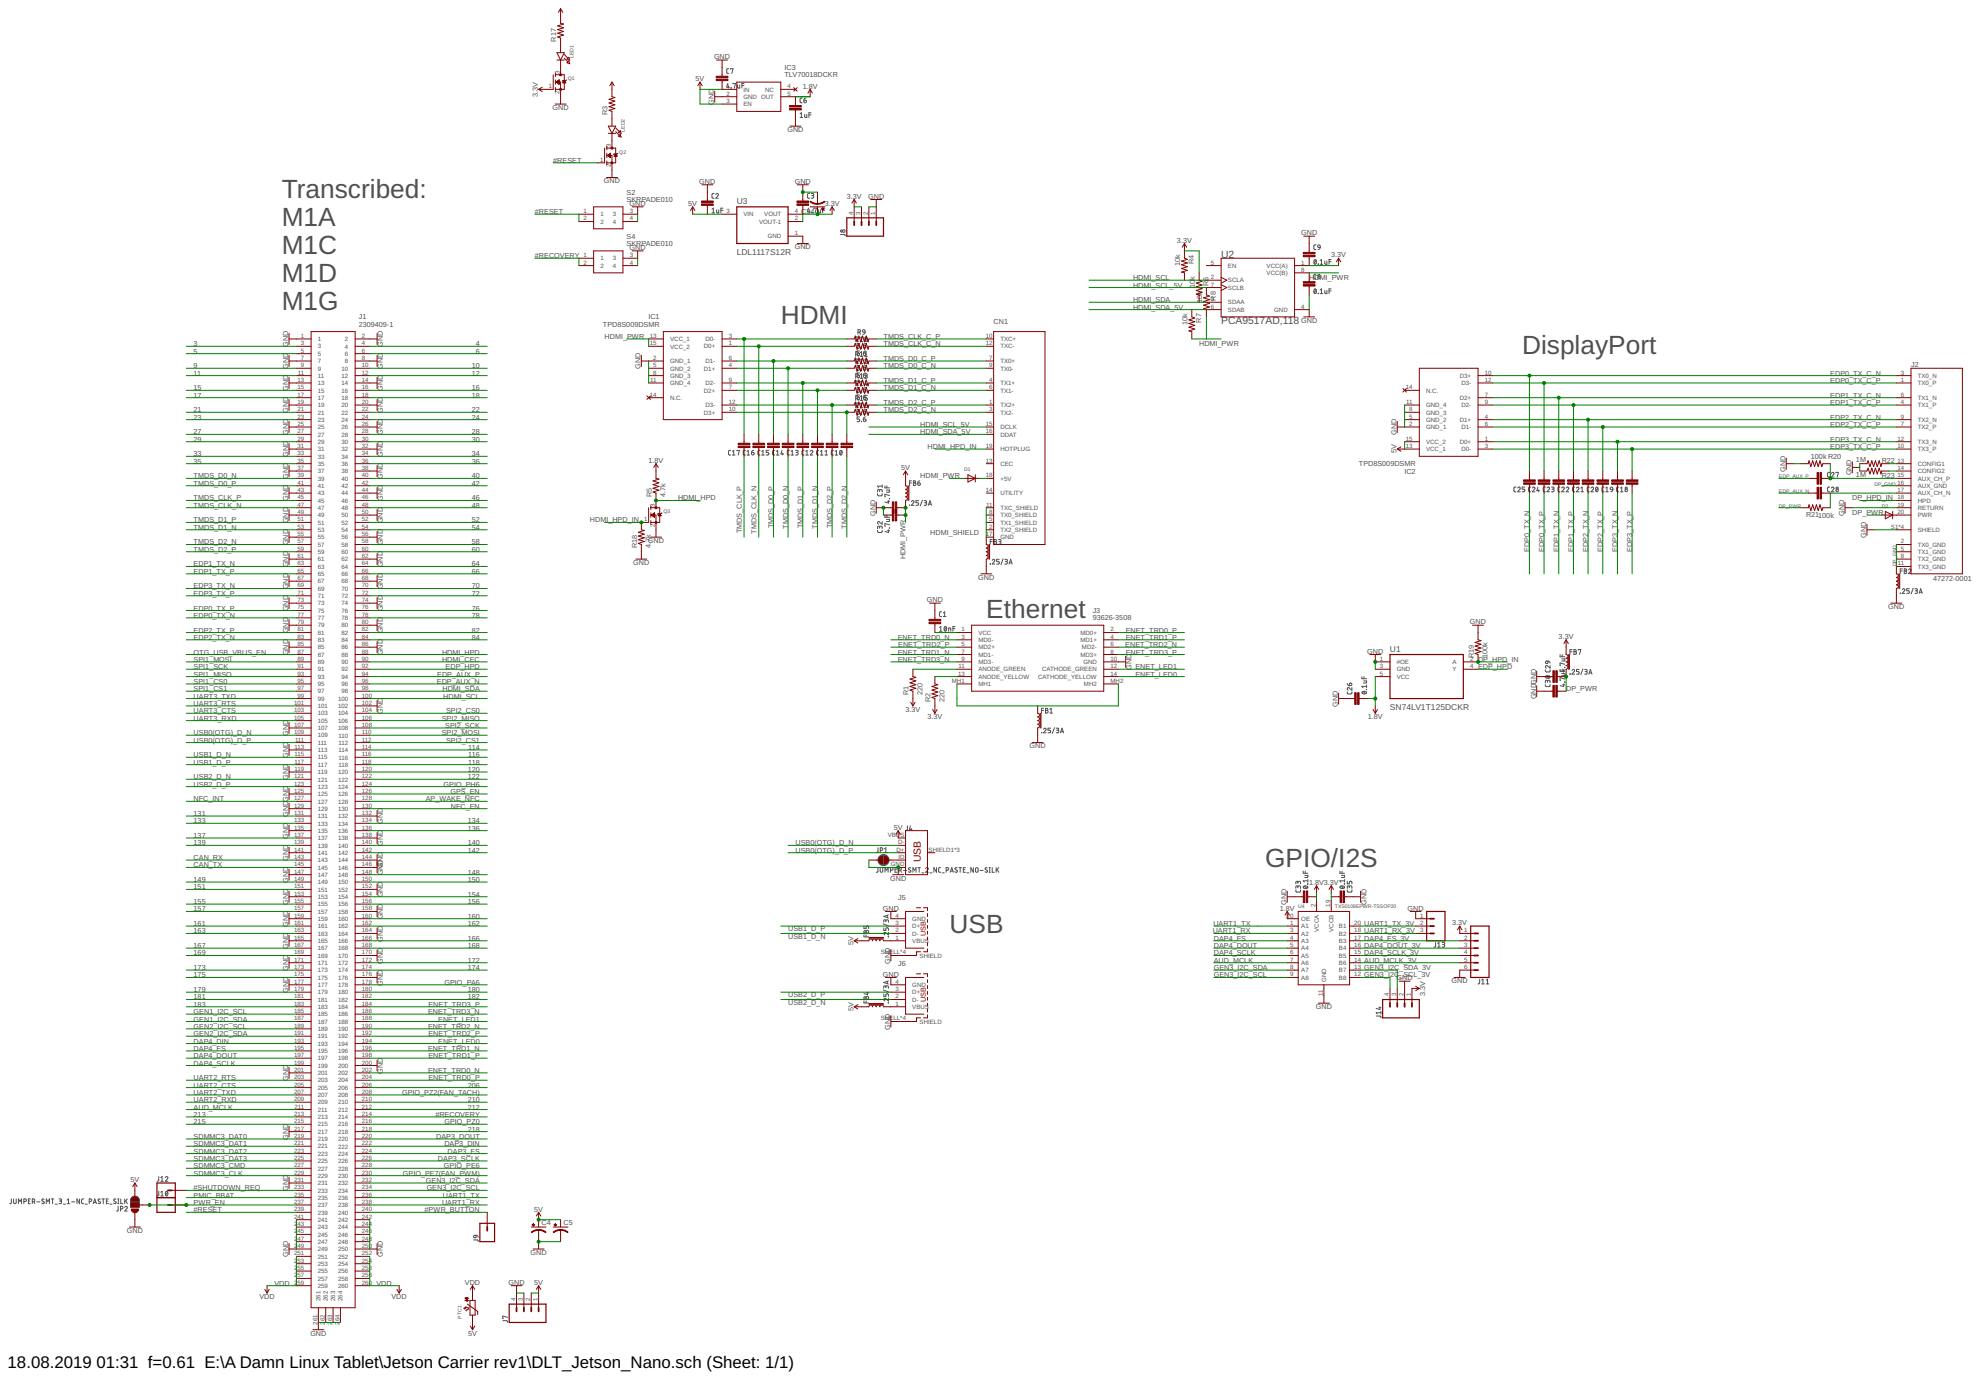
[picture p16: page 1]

GND GND

GNDGND GND GND GND

243 | 244
245 | 246
247 | 248
249 | 250
251 | 252
253 | 254
255 | 256
257 | 258
259 | 260

18.08.2019 01:31 f=0.61 E:\A Damn Linux Tablet\Jetson Carrier rev1\DLT_Jetson_Nano.sch (Sheet: 1/1)

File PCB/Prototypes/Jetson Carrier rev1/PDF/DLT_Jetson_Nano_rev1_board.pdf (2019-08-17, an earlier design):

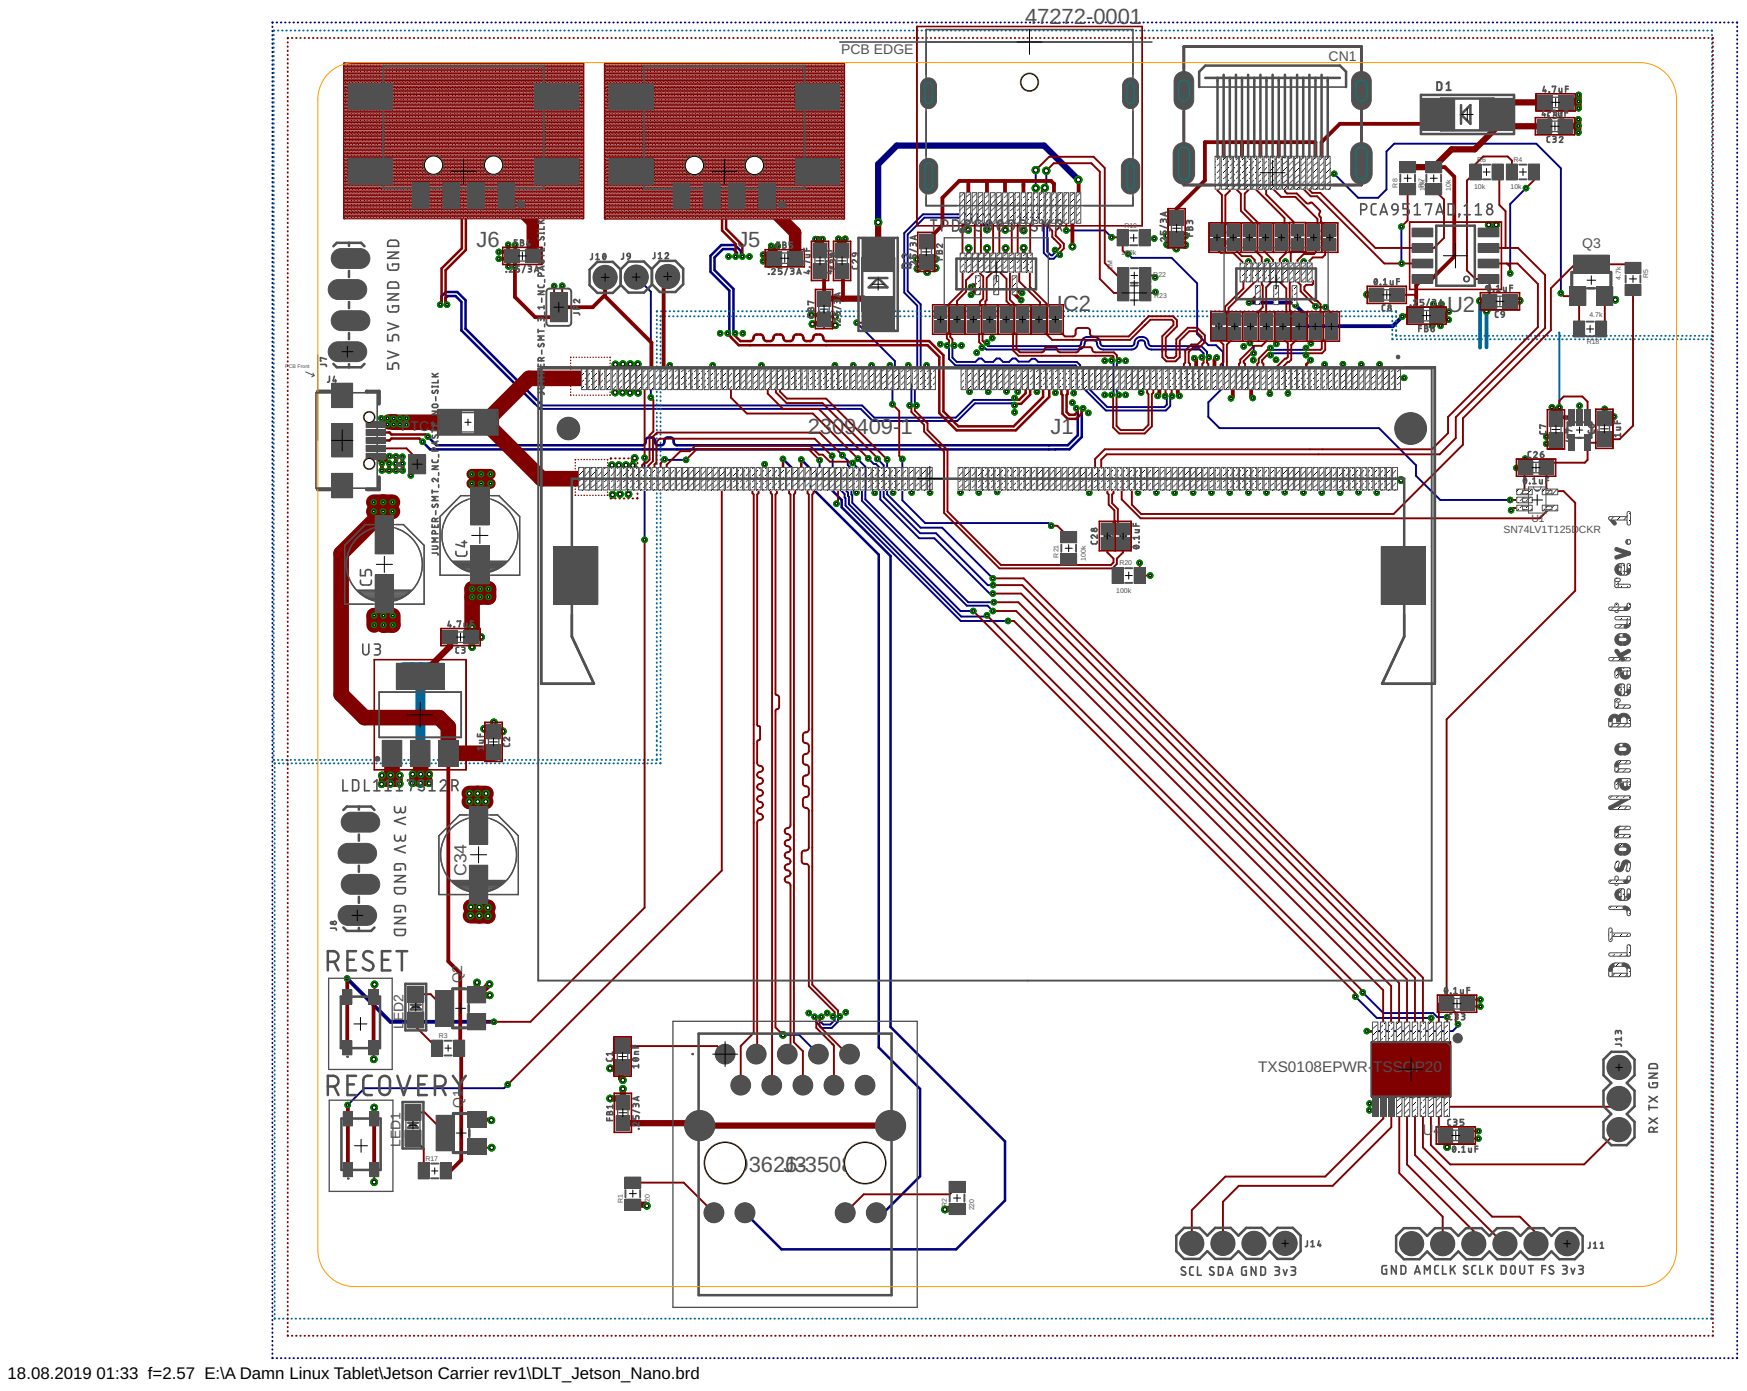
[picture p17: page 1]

18.08.2019 01:33 f=2.57 E:\A Damn Linux Tablet\Jetson Carrier rev1\DLT_Jetson_Nano.brd

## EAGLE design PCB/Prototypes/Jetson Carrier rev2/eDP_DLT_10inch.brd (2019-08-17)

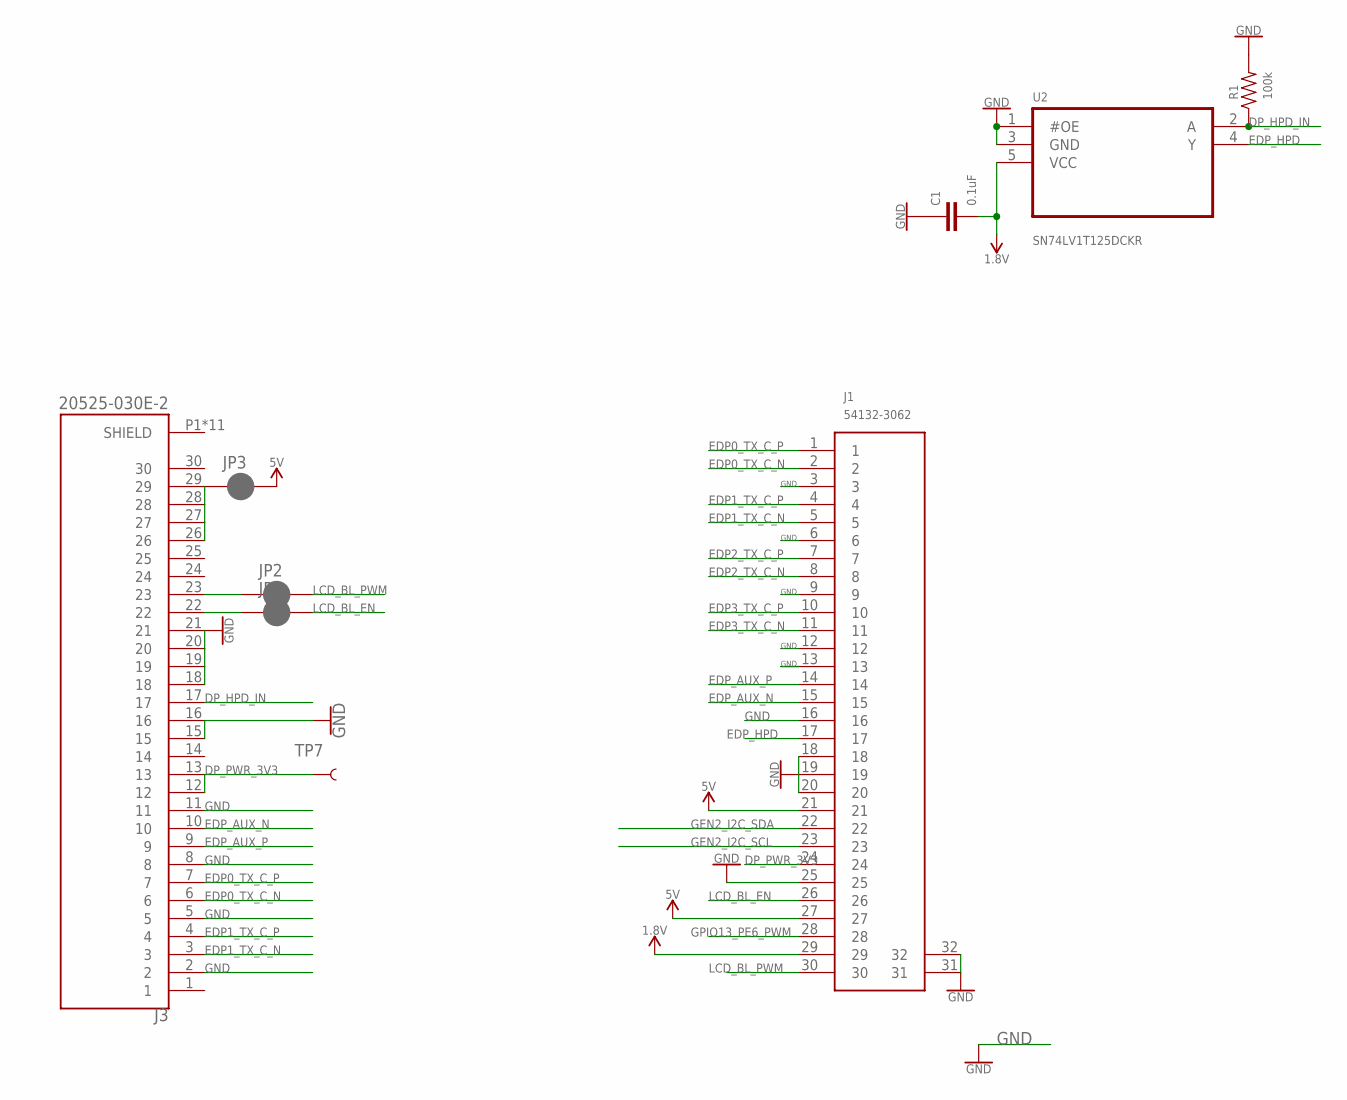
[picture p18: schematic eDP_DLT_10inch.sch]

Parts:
C1: 0.1uF; 0603
J1: 54132-3062
J3: 20525-030E-2; I-PEX_20525-030E-2
JP1, JP2, JP3: JUMPER-SMT_2_NC_PASTE_NO-SILK; SMT-JUMPER_2_NC_PASTE_NO-SILK
R1: 100k; 0603-RES
TP7: TEST-POINT3; PAD.03X.03
U2: SN74LV1T125DCKR; SOT65P210X110-5N

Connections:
1.8V: C1.2, J1.29, U2.5 (VCC)
5V: J1.21, J1.27, JP3.2
DP_HPD_IN: J3.17, R1.1, U2.2 (A)
DP_PWR_3V3: J1.24, J3.12, J3.13, TP7.P$1
EDP0_TX_C_N: J1.2, J3.6
EDP0_TX_C_P: J1.1, J3.7
EDP1_TX_C_N: J1.5, J3.3
EDP1_TX_C_P: J1.4, J3.4
EDP2_TX_C_N: J1.8
EDP2_TX_C_P: J1.7
EDP3_TX_C_N: J1.11
EDP3_TX_C_P: J1.10
EDP_AUX_N: J1.15, J3.10
EDP_AUX_P: J1.14, J3.9
EDP_HPD: J1.17, U2.4 (Y)
GEN2_I2C_SCL: J1.23
GEN2_I2C_SDA: J1.22
GND: C1.1, J1.3, J1.6, J1.9, J1.12, J1.13, J1.16, J1.18, J1.19, J1.20, J1.25, J1.31, J1.32, J3.2, J3.5, J3.8, J3.11, J3.15, J3.16, J3.18, J3.19, J3.20, J3.21, R1.2, U2.1 (#OE), U2.3 (GND)
GPIO13_PE6_PWM: J1.28
LCD_BL_EN: J1.26, JP1.2
LCD_BL_PWM: J1.30, JP2.2
unnamed: J3.22, JP1.1
unnamed: J3.23, JP2.1
unnamed: J3.26, J3.27, J3.28, J3.29, JP3.1

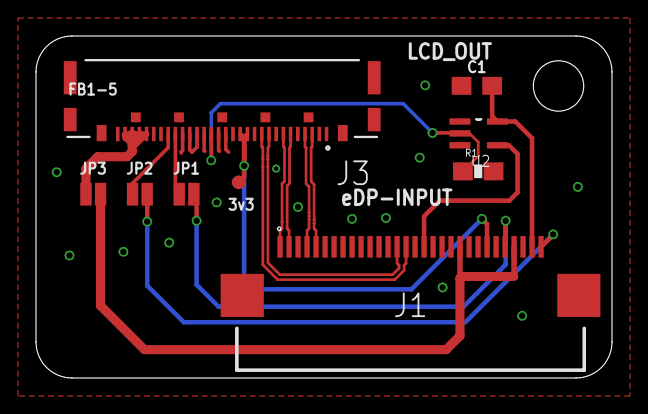
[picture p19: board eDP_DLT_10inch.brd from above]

Board: 4 copper layers, 32.0 x 19.0 mm, 9 parts (0 on the bottom side), 17 nets.

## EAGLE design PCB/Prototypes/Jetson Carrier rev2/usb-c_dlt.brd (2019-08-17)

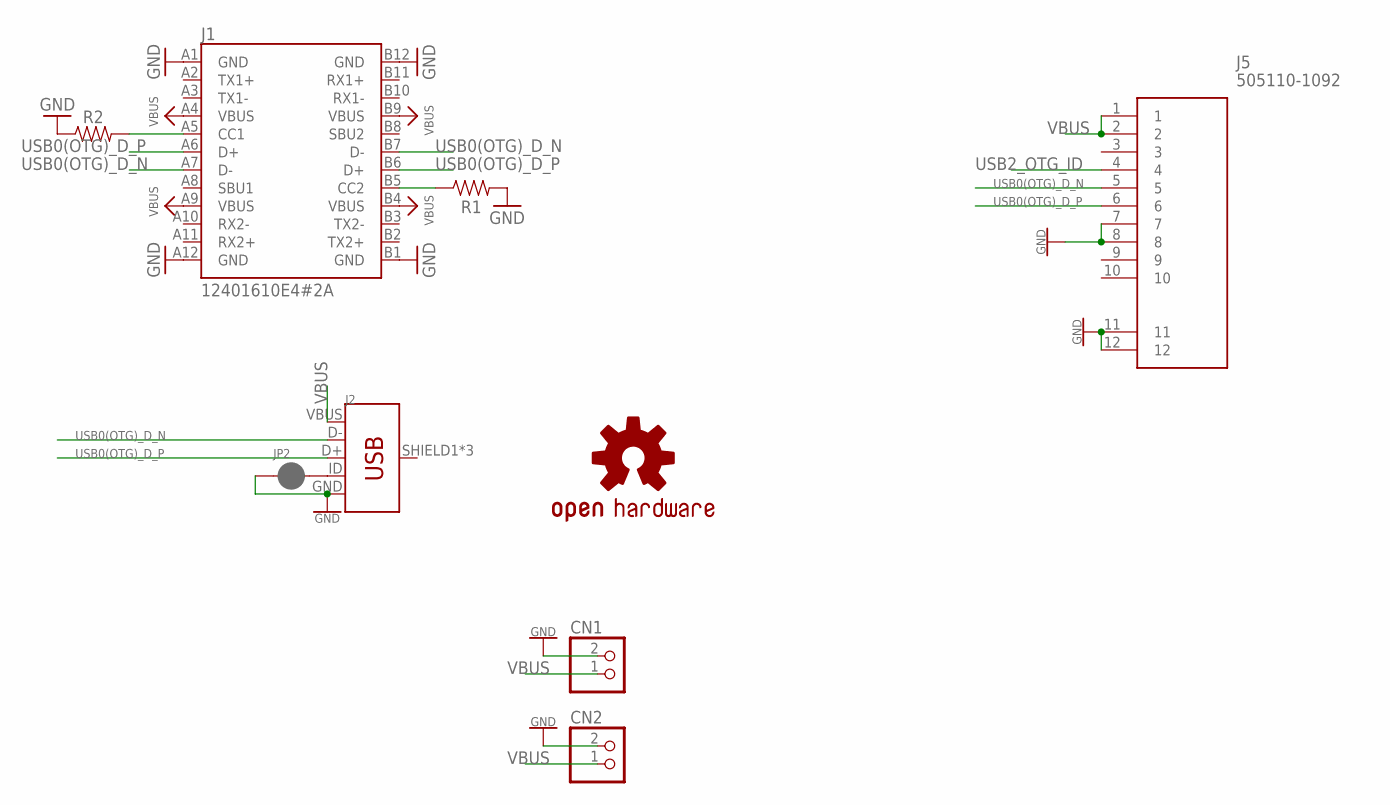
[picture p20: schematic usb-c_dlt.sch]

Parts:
CN1, CN2: JST_2PIN-SMT-RA; JST-PH-2-SMT-RA
J1: 12401610E4#2A; AMPHENOL_12401610E4#2A
J2: USB_MICRO-B_FEMALE-SMT; USB-B-MICRO-SMD
J5: 505110-1092; 5051101092
JP2: JUMPER-SMT_2_NC_PASTE_NO-SILK; SMT-JUMPER_2_NC_PASTE_NO-SILK
LOGO1: OSHW-LOGOS-COPPER; OSHW-LOGO-S_COPPER
R1, R2: 0603

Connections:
A0/CC2: J1.A5 (CC1), R2.2
A3/CC1: J1.B5 (CC2), R1.1
GND: CN1.2 (1), CN2.2 (1), J1.A1 (GND), J1.A12 (GND), J1.B1 (GND), J1.B12 (GND), J2.GND, J5.7, J5.8, J5.11, J5.12, JP2.1, R1.2, R2.1
unnamed: J2.ID, JP2.2
USB0(OTG)_D_N: J1.A7 (D-), J1.B7 (D-), J2.D-, J5.5
USB0(OTG)_D_P: J1.A6 (D+), J1.B6 (D+), J2.D+, J5.6
USB2_OTG_ID: J5.4
VBUS: CN1.1 (2), CN2.1 (2), J1.A4 (VBUS), J1.A9 (VBUS), J1.B4 (VBUS), J1.B9 (VBUS), J2.VBUS, J5.1, J5.2

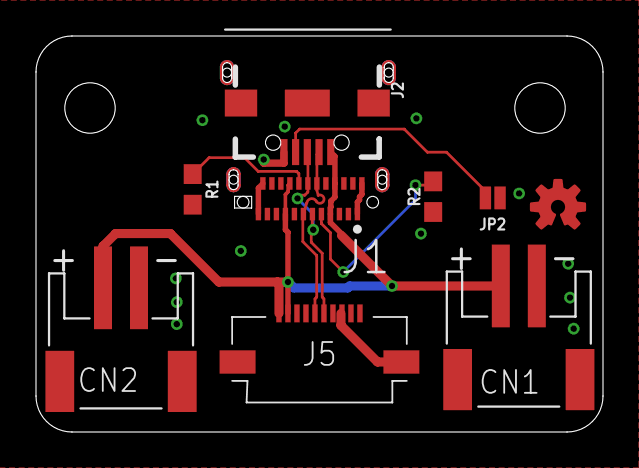
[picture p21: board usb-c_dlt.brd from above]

Board: 2 copper layers, 31.5 x 22.0 mm, 9 parts (0 on the bottom side), 7 nets.

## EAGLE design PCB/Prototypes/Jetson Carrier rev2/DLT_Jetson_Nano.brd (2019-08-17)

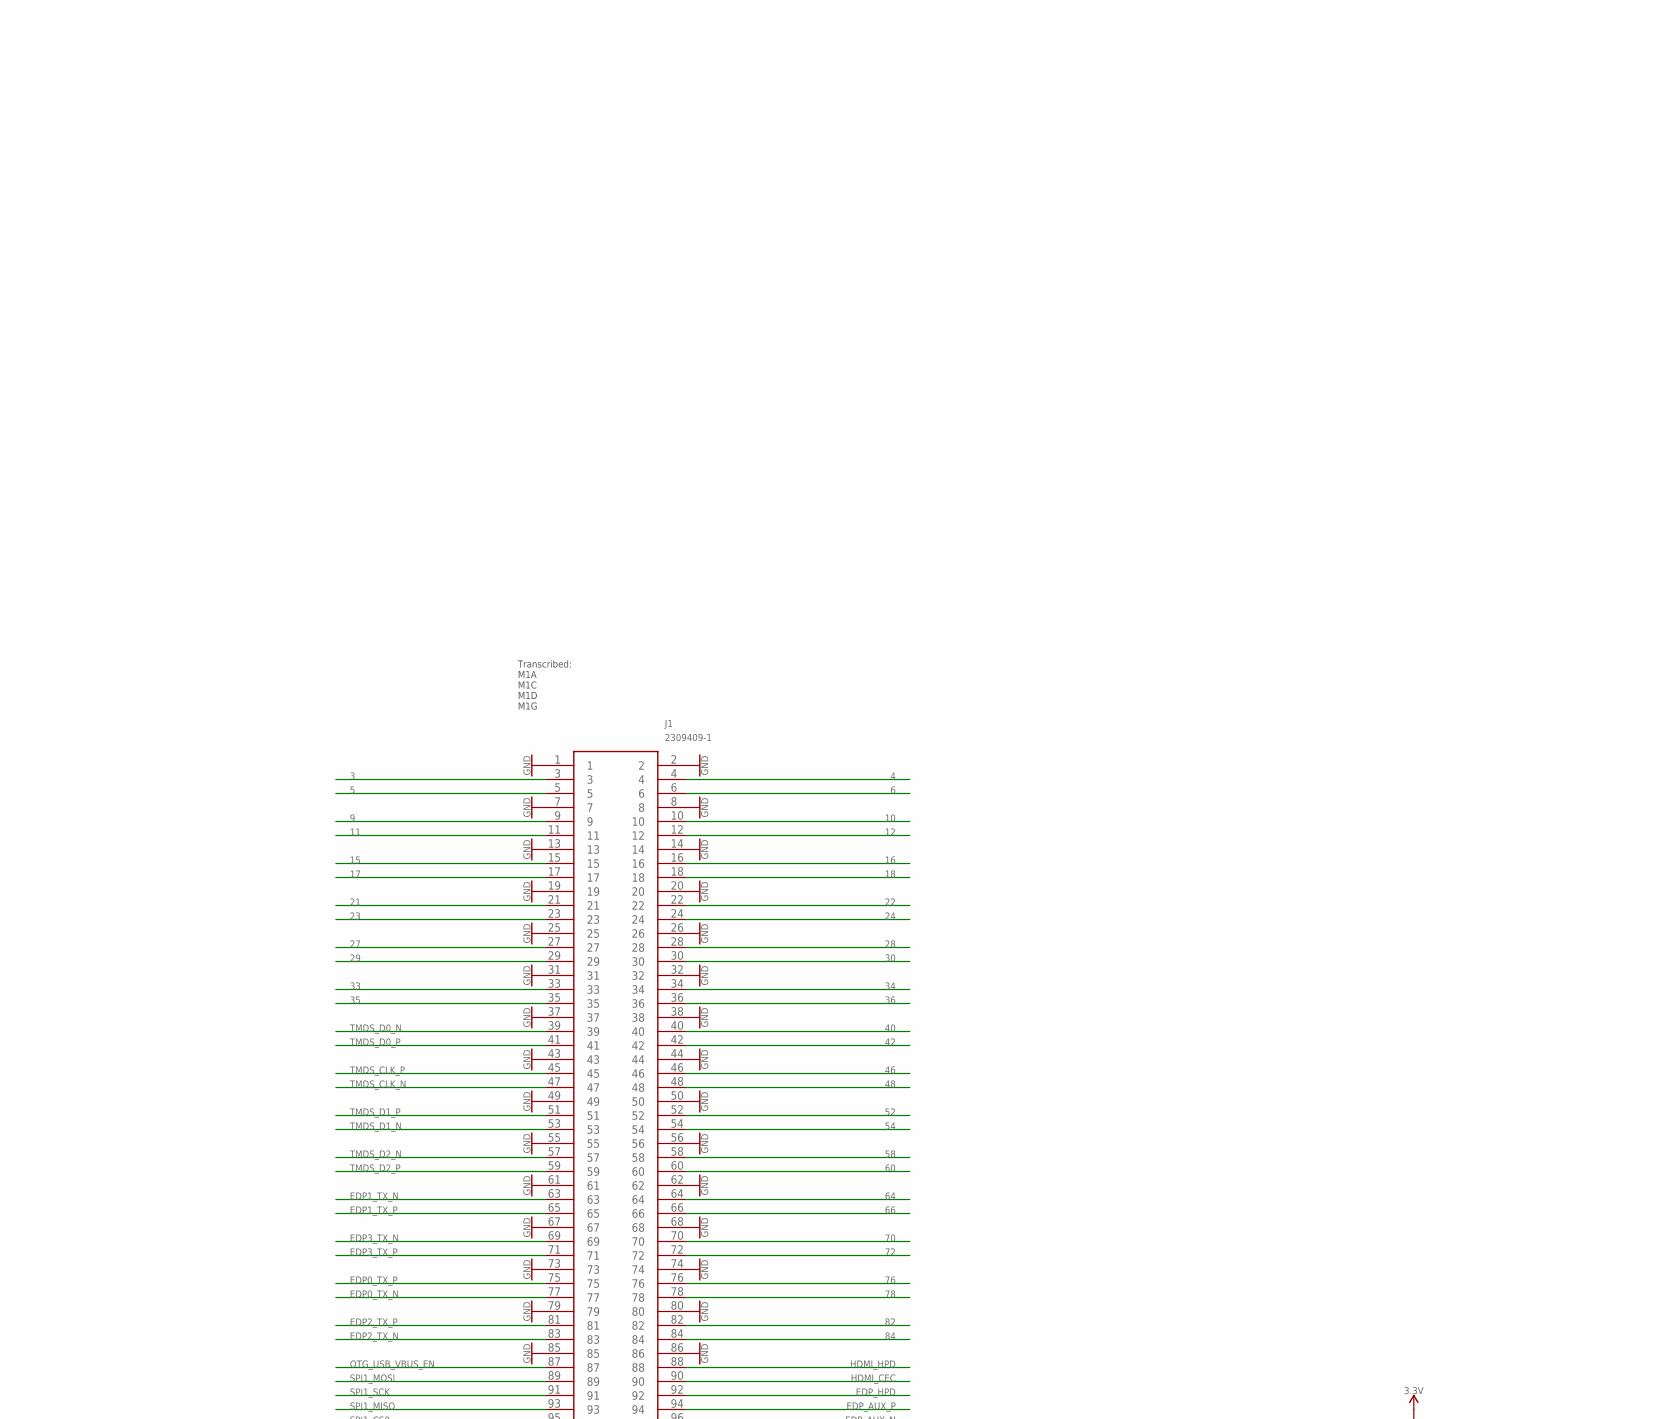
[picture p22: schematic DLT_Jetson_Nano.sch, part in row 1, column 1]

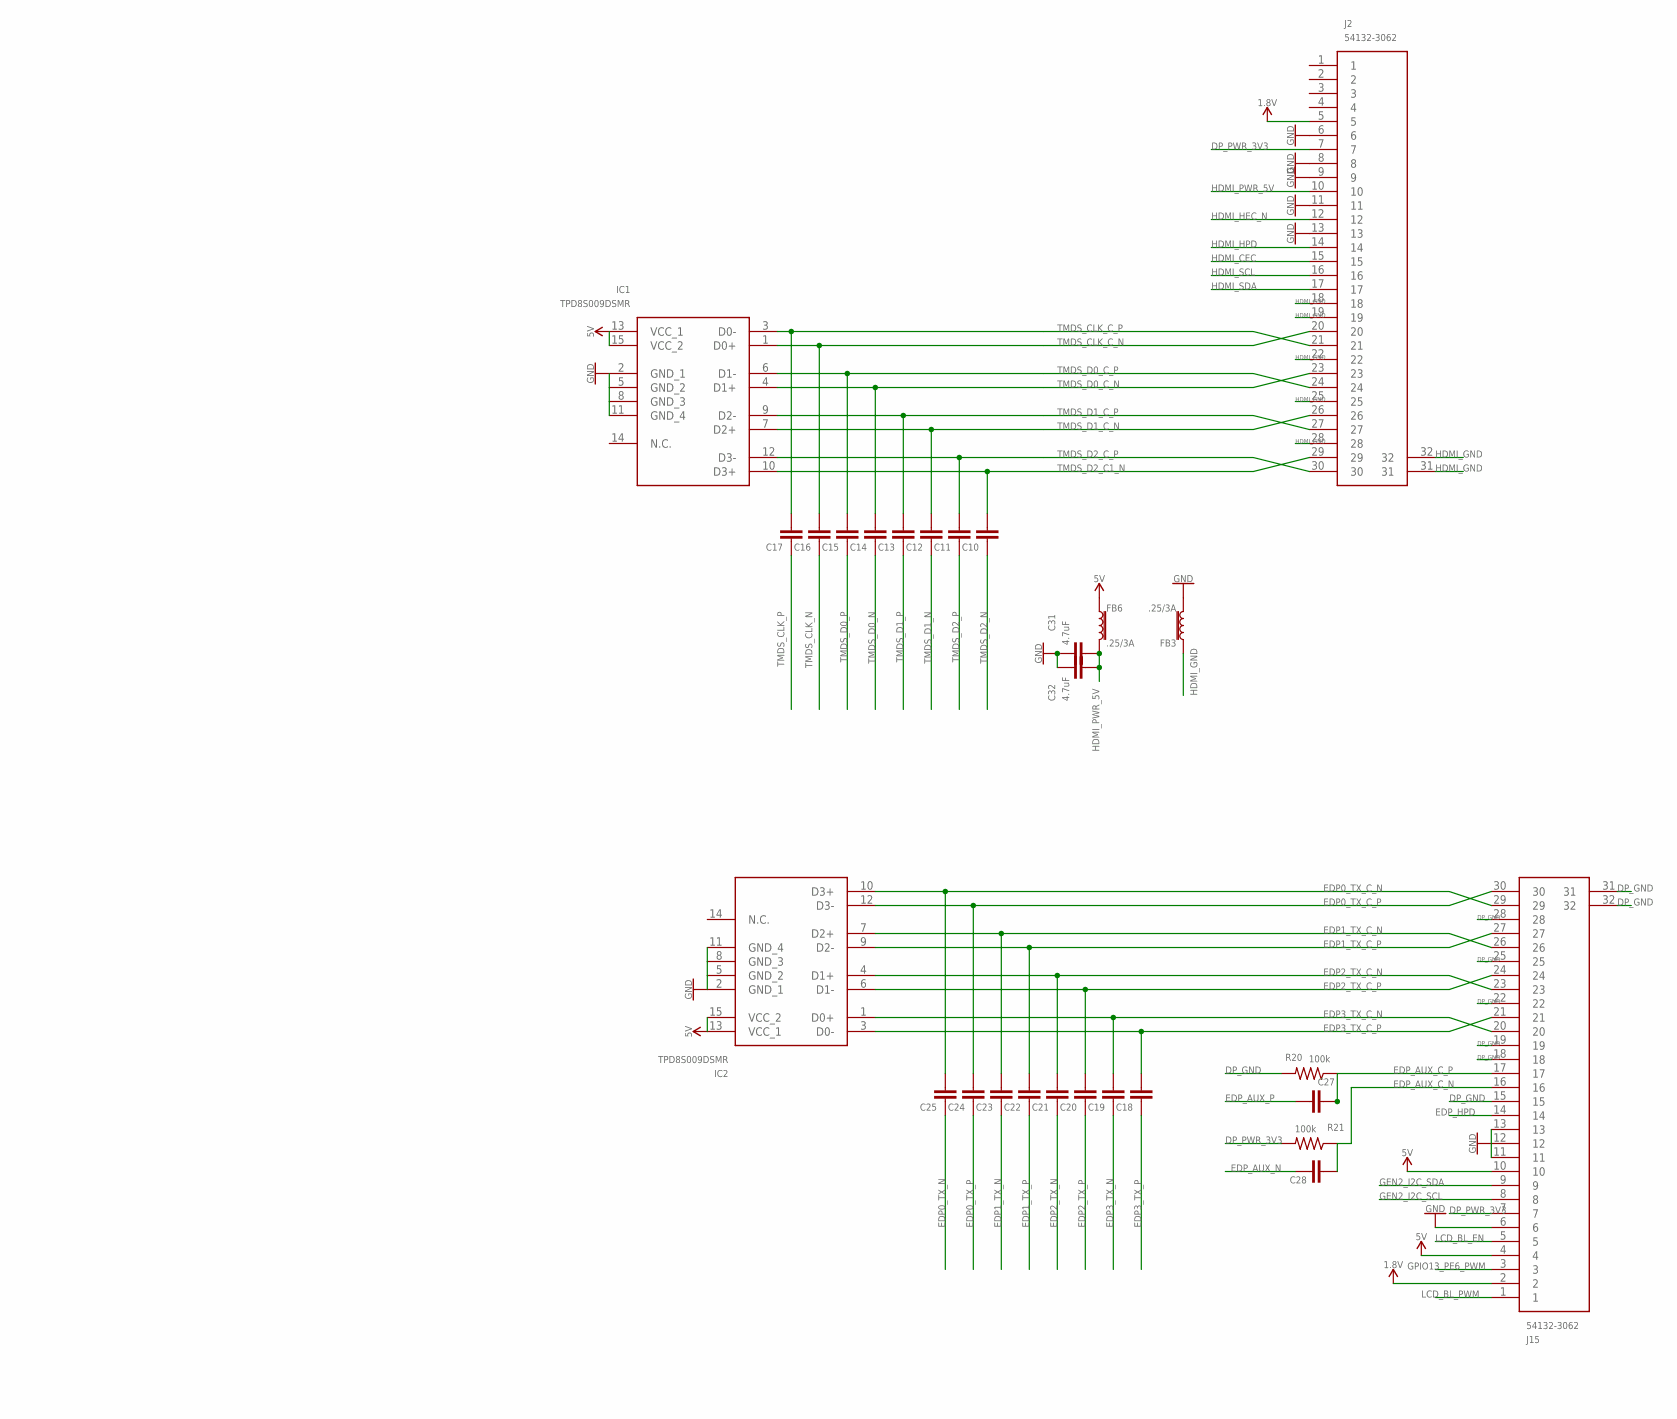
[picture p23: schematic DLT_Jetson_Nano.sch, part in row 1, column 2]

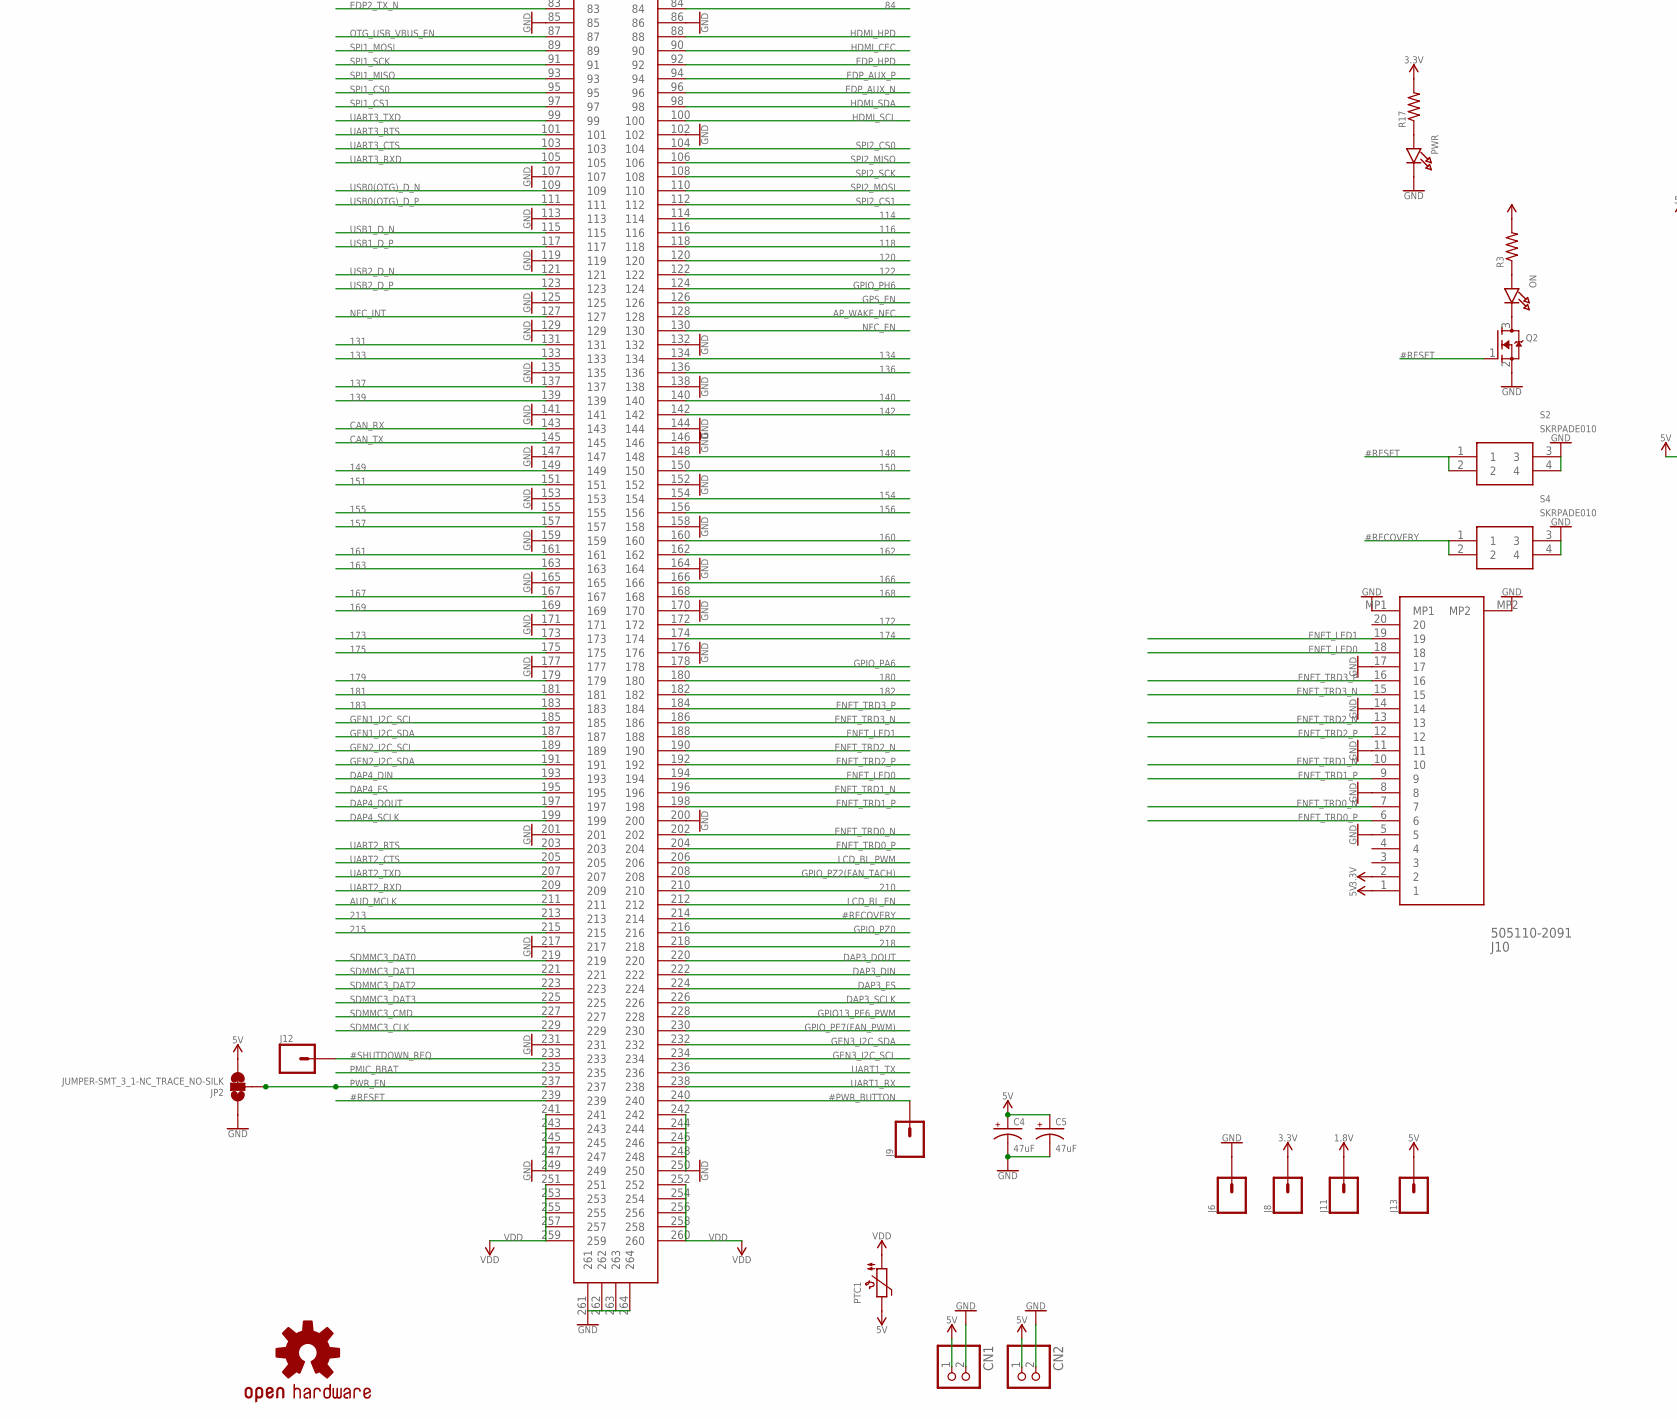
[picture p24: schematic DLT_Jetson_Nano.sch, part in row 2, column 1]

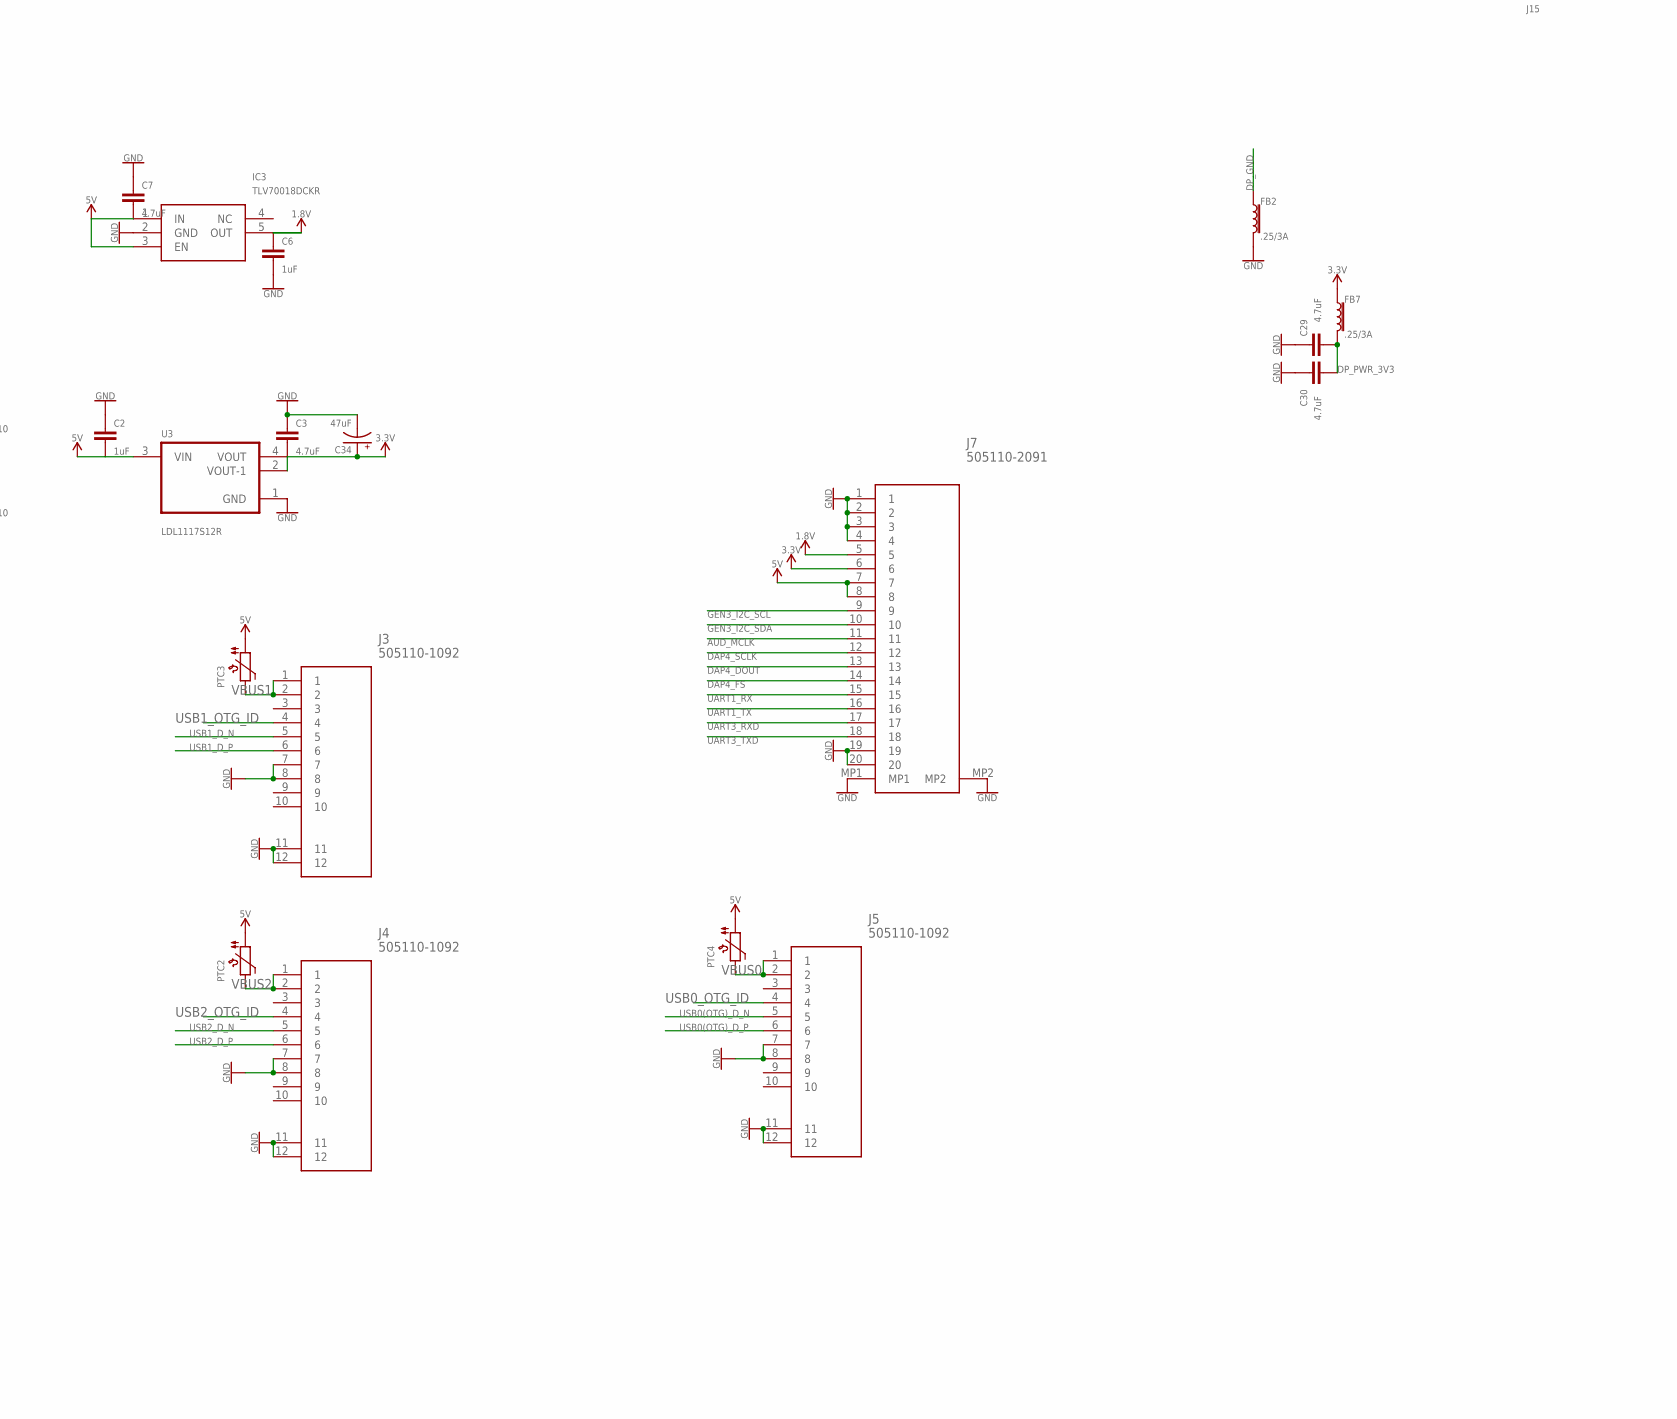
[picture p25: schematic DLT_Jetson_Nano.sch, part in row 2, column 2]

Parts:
C2, C6: 1uF; 0603
C3, C7, C29, C30, C31, C32: 4.7uF; 0603
C4, C5, C34: 47uF; EIA3528
C10, C11, C12, C13, C14, C15, C16, C17, C18, C19, C20, C21, C22, C23, C24, C25, C27, C28: 0.1uF; 0402
CN1, CN2: JST_2PIN-SMT-RA; JST-PH-2-SMT-RA
FB2, FB3, FB6, FB7: .25/3A; 0603
IC1, IC2: TPD8S009DSMR
IC3: TLV70018DCKR; SOT65P210X110-5N
J1: 2309409-1
J2, J15: 54132-3062
J3, J4, J5: 505110-1092; 5051101092
J6, J8, J9, J11, J12, J13: CONN_01; 1X01
J7, J10: 505110-2091; 5051102091
JP2: JUMPER-SMT_3_1-NC_TRACE_NO-SILK; SMT-JUMPER_3_1-NC_TRACE_NO-SILK
LOGO1: OSHW-LOGOS-COPPER; OSHW-LOGO-S_COPPER
ON: LED0805; CHIPLED_0805
PTC1, PTC2, PTC3, PTC4: PTC1206; 1206
PWR: LED0805; CHIPLED_0805
Q2: MOSFET-NWAVE; SOT23-W
R3, R17: RESISTOR0805-RES; 0805
R20, R21: 100k; 0805
S2, S4: SKRPADE010
U3: LDL1117S12R; SOT230P700X180-4N

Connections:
1.8V: C6.1, IC3.5 (OUT), J2.5, J7.5, J11.1, J15.2
3: J1.3
3.3V: C3.2, C34.A (+), FB7.1, J7.6, J8.1, J10.2, R17.2, U3.2 (VOUT-1), U3.4 (VOUT)
4: J1.4
5: J1.5
5V: C2.2, C4.A (+), C5.A (+), C7.2, CN1.1 (2), CN2.1 (2), FB6.1, IC1.13 (VCC_1), IC1.15 (VCC_2), IC2.13 (VCC_1), IC2.15 (VCC_2), IC3.1 (IN), IC3.3 (EN), J7.7, J7.8, J10.1, J13.1, J15.4, J15.10, JP2.3, PTC1.2, PTC2.1, PTC3.1, PTC4.1, R3.2, U3.3 (VIN)
6: J1.6
9: J1.9
10: J1.10
11: J1.11
12: J1.12
15: J1.15
16: J1.16
17: J1.17
18: J1.18
21: J1.21
22: J1.22
23: J1.23
24: J1.24
27: J1.27
28: J1.28
29: J1.29
30: J1.30
33: J1.33
34: J1.34
35: J1.35
36: J1.36
40: J1.40
42: J1.42
46: J1.46
48: J1.48
52: J1.52
54: J1.54
58: J1.58
60: J1.60
64: J1.64
66: J1.66
70: J1.70
72: J1.72
76: J1.76
78: J1.78
82: J1.82
84: J1.84
114: J1.114
116: J1.116
118: J1.118
120: J1.120
122: J1.122
131: J1.131
133: J1.133
134: J1.134
136: J1.136
137: J1.137
139: J1.139
140: J1.140
142: J1.142
148: J1.148
149: J1.149
150: J1.150
151: J1.151
154: J1.154
155: J1.155
156: J1.156
157: J1.157
160: J1.160
161: J1.161
162: J1.162
163: J1.163
166: J1.166
167: J1.167
168: J1.168
169: J1.169
172: J1.172
173: J1.173
174: J1.174
175: J1.175
179: J1.179
180: J1.180
181: J1.181
182: J1.182
183: J1.183
210: J1.210
213: J1.213
215: J1.215
218: J1.218
#PWR_BUTTON: J1.240, J9.1
#RECOVERY: J1.214, S4.1, S4.2
#RESET: J1.239, Q2.1 (G), S2.1, S2.2
#SHUTDOWN_REQ: J1.233, J12.1
AP_WAKE_NFC: J1.128
AUD_MCLK: J1.211, J7.11
CAN_RX: J1.143
CAN_TX: J1.145
DAP3_DIN: J1.222
DAP3_DOUT: J1.220
DAP3_FS: J1.224
DAP3_SCLK: J1.226
DAP4_DIN: J1.193
DAP4_DOUT: J1.197, J7.13
DAP4_FS: J1.195, J7.14
DAP4_SCLK: J1.199, J7.12
DP_GND: FB2.1, J15.15, J15.18, J15.19, J15.22, J15.25, J15.28, J15.31, J15.32, R20.2
DP_PWR_3V3: C29.2, C30.2, FB7.2, J2.7, J15.7, R21.2
EDP0_TX_C_N: C25.2, IC2.10 (D3+), J15.29
EDP0_TX_C_P: C24.2, IC2.12 (D3-), J15.30
EDP0_TX_N: C25.1, J1.77
EDP0_TX_P: C24.1, J1.75
EDP1_TX_C_N: C23.2, IC2.7 (D2+), J15.26
EDP1_TX_C_P: C22.2, IC2.9 (D2-), J15.27
EDP1_TX_N: C23.1, J1.63
EDP1_TX_P: C22.1, J1.65
EDP2_TX_C_N: C21.2, IC2.4 (D1+), J15.23
EDP2_TX_C_P: C20.2, IC2.6 (D1-), J15.24
EDP2_TX_N: C21.1, J1.83
EDP2_TX_P: C20.1, J1.81
EDP3_TX_C_N: C19.2, IC2.1 (D0+), J15.20
EDP3_TX_C_P: C18.2, IC2.3 (D0-), J15.21
EDP3_TX_N: C19.1, J1.69
EDP3_TX_P: C18.1, J1.71
EDP_AUX_C_N: C28.1, J15.16, R21.1
EDP_AUX_C_P: C27.1, J15.17, R20.1
EDP_AUX_N: C28.2, J1.96
EDP_AUX_P: C27.2, J1.94
EDP_HPD: J1.92, J15.14
ENET_LED0: J1.194, J10.18
ENET_LED1: J1.188, J10.19
ENET_TRD0_N: J1.202, J10.7
ENET_TRD0_P: J1.204, J10.6
ENET_TRD1_N: J1.196, J10.10
ENET_TRD1_P: J1.198, J10.9
ENET_TRD2_N: J1.190, J10.13
ENET_TRD2_P: J1.192, J10.12
ENET_TRD3_N: J1.186, J10.15
ENET_TRD3_P: J1.184, J10.16
GEN1_I2C_SCL: J1.185
GEN1_I2C_SDA: J1.187
GEN2_I2C_SCL: J1.189, J15.8
GEN2_I2C_SDA: J1.191, J15.9
GEN3_I2C_SCL: J1.234, J7.9
GEN3_I2C_SDA: J1.232, J7.10
GND: C2.1, C3.1, C4.C (-), C5.C (-), C6.2, C7.1, C29.1, C30.1, C31.1, C32.1, C34.C (-), CN1.2 (1), CN2.2 (1), FB2.2, FB3.2, IC1.2 (GND_1), IC1.5 (GND_2), IC1.8 (GND_3), IC1.11 (GND_4), IC2.2 (GND_1), IC2.5 (GND_2), IC2.8 (GND_3), IC2.11 (GND_4), IC3.2 (GND), J1.1, J1.2, J1.7, J1.8, J1.13, J1.14, J1.19, J1.20, J1.25, J1.26, J1.31, J1.32, J1.37, J1.38, J1.43, J1.44, J1.49, J1.50, J1.55, J1.56, J1.61, J1.62, J1.67, J1.68, J1.73, J1.74, J1.79, J1.80, J1.85, J1.86, J1.102, J1.107, J1.113, J1.119, J1.125, J1.129, J1.132, J1.135, J1.138, J1.141, J1.144, J1.146, J1.147, J1.152, J1.153, J1.158, J1.159, J1.164, J1.165, J1.170, J1.171, J1.176, J1.177, J1.200, J1.201, J1.217, J1.231, J1.241, J1.242, J1.243, J1.244, J1.245, J1.246, J1.247, J1.248, J1.249, J1.250, J1.261, J1.262, J1.263, J1.264, J2.6, J2.8, J2.9, J2.11, J2.13, J3.7, J3.8, J3.11, J3.12, J4.7, J4.8, J4.11, J4.12, J5.7, J5.8, J5.11, J5.12, J6.1, J7.1, J7.2, J7.3, J7.4, J7.19, J7.20, J7.MP1, J7.MP2, J10.5, J10.8, J10.11, J10.14, J10.17, J10.MP1, J10.MP2, J15.6, J15.11, J15.12, J15.13, JP2.1, PWR.C, Q2.2 (S), S2.3, S2.4, S4.3, S4.4, U3.1 (GND)
GPIO13_PE6_PWM: J1.228, J15.3
GPIO_PA6: J1.178
GPIO_PE7(FAN_PWM): J1.230
GPIO_PH6: J1.124
GPIO_PZ0: J1.216
GPIO_PZ2(FAN_TACH): J1.208
GPS_EN: J1.126
HDMI_CEC: J1.90, J2.15
HDMI_GND: FB3.1, J2.18, J2.19, J2.22, J2.25, J2.28, J2.31, J2.32
HDMI_HEC_N: J2.12
HDMI_HPD: J1.88, J2.14
HDMI_PWR_5V: C31.2, C32.2, FB6.2, J2.10
HDMI_SCL: J1.100, J2.16
HDMI_SDA: J1.98, J2.17
LCD_BL_EN: J1.212, J15.5
LCD_BL_PWM: J1.206, J15.1
unnamed: ON.C, Q2.3 (D)
unnamed: ON.A, R3.1
unnamed: PWR.A, R17.1
NFC_EN: J1.130
NFC_INT: J1.127
OTG_USB_VBUS_EN: J1.87
PMIC_BBAT: J1.235
PWR_EN: J1.237, JP2.2
SDMMC3_CLK: J1.229
SDMMC3_CMD: J1.227
SDMMC3_DAT0: J1.219
SDMMC3_DAT1: J1.221
SDMMC3_DAT2: J1.223
SDMMC3_DAT3: J1.225
SPI1_CS0: J1.95
SPI1_CS1: J1.97
SPI1_MISO: J1.93
SPI1_MOSI: J1.89
SPI1_SCK: J1.91
SPI2_CS0: J1.104
SPI2_CS1: J1.112
SPI2_MISO: J1.106
SPI2_MOSI: J1.110
SPI2_SCK: J1.108
TMDS_CLK_C_N: C16.2, IC1.1 (D0+), J2.20
TMDS_CLK_C_P: C17.2, IC1.3 (D0-), J2.21
TMDS_CLK_N: C16.1, J1.47
TMDS_CLK_P: C17.1, J1.45
TMDS_D0_C_N: C14.2, IC1.4 (D1+), J2.23
TMDS_D0_C_P: C15.2, IC1.6 (D1-), J2.24
TMDS_D0_N: C14.1, J1.39
TMDS_D0_P: C15.1, J1.41
TMDS_D1_C_N: C12.2, IC1.7 (D2+), J2.26
TMDS_D1_C_P: C13.2, IC1.9 (D2-), J2.27
TMDS_D1_N: C12.1, J1.53
TMDS_D1_P: C13.1, J1.51
TMDS_D2_C1_N: C10.2, IC1.10 (D3+), J2.29
TMDS_D2_C_P: C11.2, IC1.12 (D3-), J2.30
TMDS_D2_N: C10.1, J1.57
TMDS_D2_P: C11.1, J1.59
UART1_RX: J1.238, J7.15
UART1_TX: J1.236, J7.16
UART2_CTS: J1.205
UART2_RTS: J1.203
UART2_RXD: J1.209
UART2_TXD: J1.207
UART3_CTS: J1.103
UART3_RTS: J1.101
UART3_RXD: J1.105, J7.17
UART3_TXD: J1.99, J7.18
USB0(OTG)_D_N: J1.109, J5.5
USB0(OTG)_D_P: J1.111, J5.6
USB0_OTG_ID: J5.4
USB1_D_N: J1.115, J3.5
USB1_D_P: J1.117, J3.6
USB1_OTG_ID: J3.4
USB2_D_N: J1.121, J4.5
USB2_D_P: J1.123, J4.6
USB2_OTG_ID: J4.4
VBUS0: J5.1, J5.2, PTC4.2
VBUS1: J3.1, J3.2, PTC3.2
VBUS2: J4.1, J4.2, PTC2.2
VDD: J1.251, J1.252, J1.253, J1.254, J1.255, J1.256, J1.257, J1.258, J1.259, J1.260, PTC1.1

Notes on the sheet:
Transcribed: M1A M1C M1D M1G

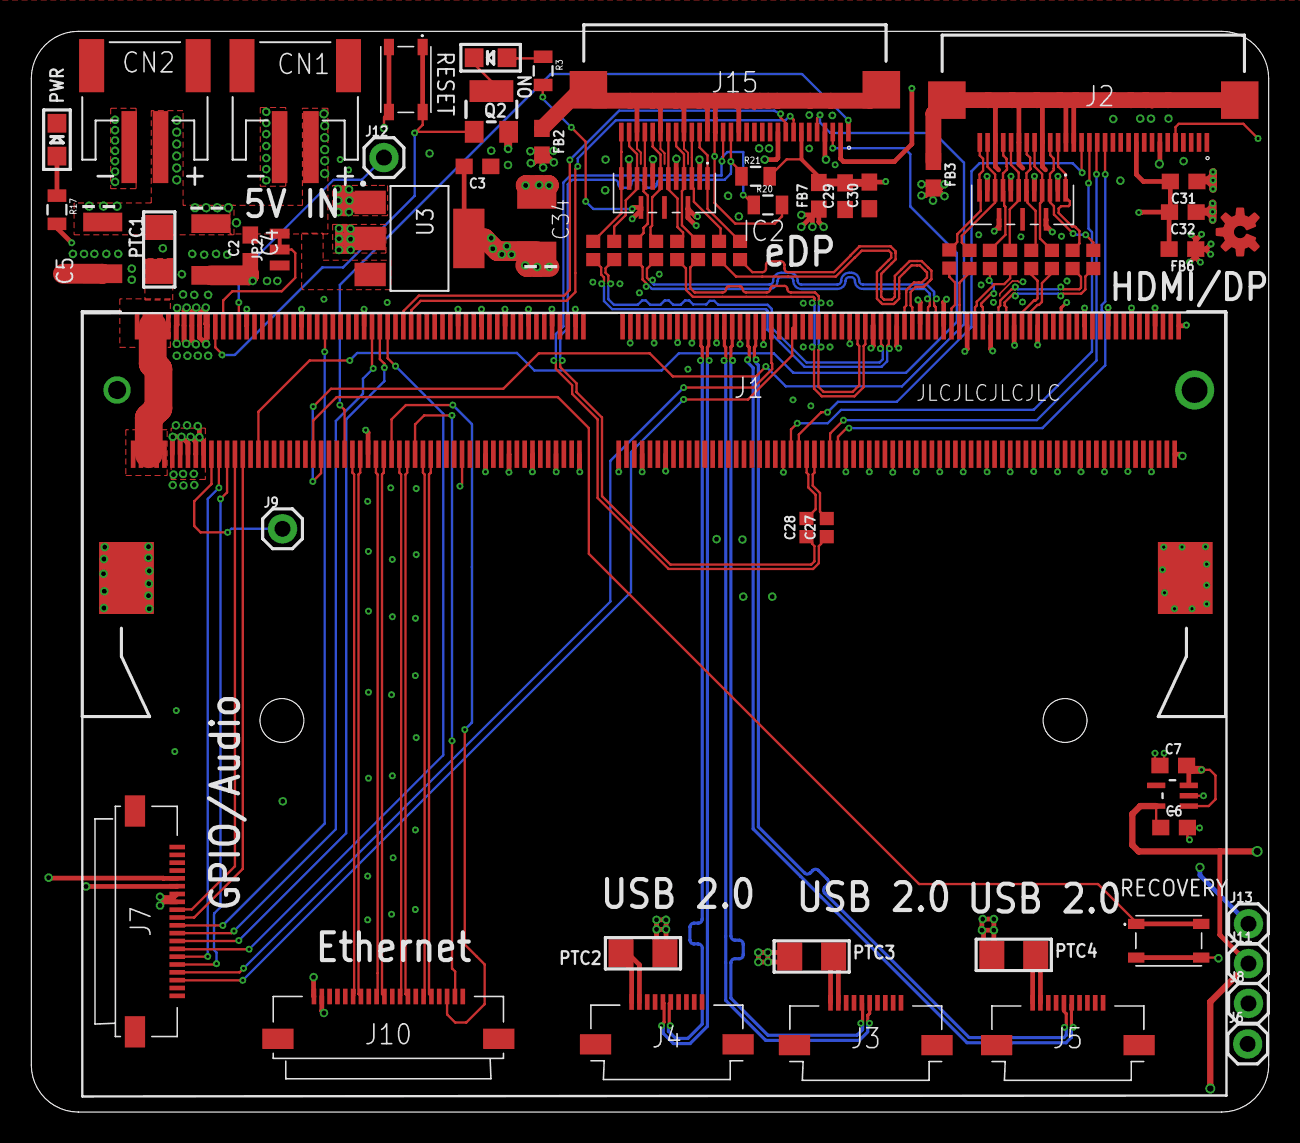
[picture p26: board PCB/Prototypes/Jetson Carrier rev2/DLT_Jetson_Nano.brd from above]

Board: 4 copper layers, 79.0 x 69.0 mm, 68 parts (0 on the bottom side), 92 nets.

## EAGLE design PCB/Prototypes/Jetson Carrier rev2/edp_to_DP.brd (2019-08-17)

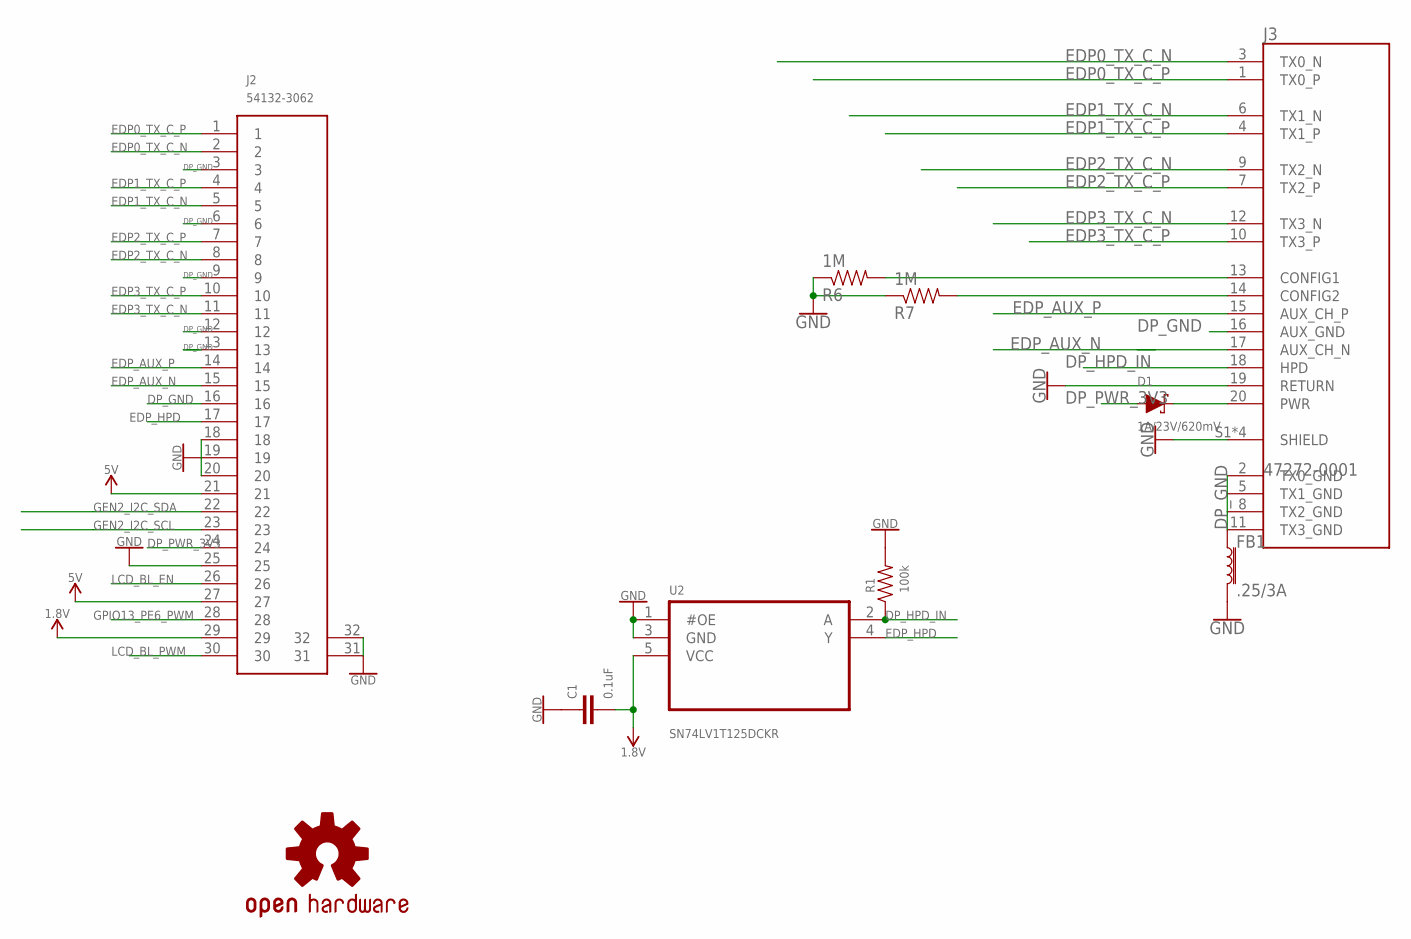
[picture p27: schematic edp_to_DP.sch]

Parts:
C1: 0.1uF; 0603
D1: 1A/23V/620mV; SOD-323
FB1: .25/3A; 0603
J2: 54132-3062
J3: 47272-0001; MOLEX_47272-0001
LOGO1: OSHW-LOGOS-COPPER; OSHW-LOGO-S_COPPER
R1: 100k; 0805
R6, R7: 1M; 0805
U2: SN74LV1T125DCKR; SOT65P210X110-5N

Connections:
1.8V: C1.2, J2.29, U2.5 (VCC)
3V3: D1.C, J3.20 (PWR)
5V: J2.21, J2.27
CONFIG3: J3.13 (CONFIG1), R6.2
CONFIG4: J3.14 (CONFIG2), R7.2
DP_GND: FB1.1, J2.3, J2.6, J2.9, J2.12, J2.13, J2.16, J3.2 (TX0_GND), J3.5 (TX1_GND), J3.8 (TX2_GND), J3.11 (TX3_GND), J3.16 (AUX_GND)
DP_HPD_IN: J3.18 (HPD), R1.1, U2.2 (A)
DP_PWR_3V3: D1.A, J2.24
EDP0_TX_C_N: J2.2, J3.3 (TX0_N)
EDP0_TX_C_P: J2.1, J3.1 (TX0_P)
EDP1_TX_C_N: J2.5, J3.6 (TX1_N)
EDP1_TX_C_P: J2.4, J3.4 (TX1_P)
EDP2_TX_C_N: J2.8, J3.9 (TX2_N)
EDP2_TX_C_P: J2.7, J3.7 (TX2_P)
EDP3_TX_C_N: J2.11, J3.12 (TX3_N)
EDP3_TX_C_P: J2.10, J3.10 (TX3_P)
EDP_AUX_N: J2.15, J3.17 (AUX_CH_N)
EDP_AUX_P: J2.14, J3.15 (AUX_CH_P)
EDP_HPD: J2.17, U2.4 (Y)
GEN2_I2C_SCL: J2.23
GEN2_I2C_SDA: J2.22
GND: C1.1, FB1.2, J2.18, J2.19, J2.20, J2.25, J2.31, J2.32, J3.19 (RETURN), J3.S1 (SHIELD), J3.S2 (SHIELD), J3.S3 (SHIELD), J3.S4 (SHIELD), R1.2, R6.1, R7.1, U2.1 (#OE), U2.3 (GND)
GPIO13_PE6_PWM: J2.28
LCD_BL_EN: J2.26
LCD_BL_PWM: J2.30

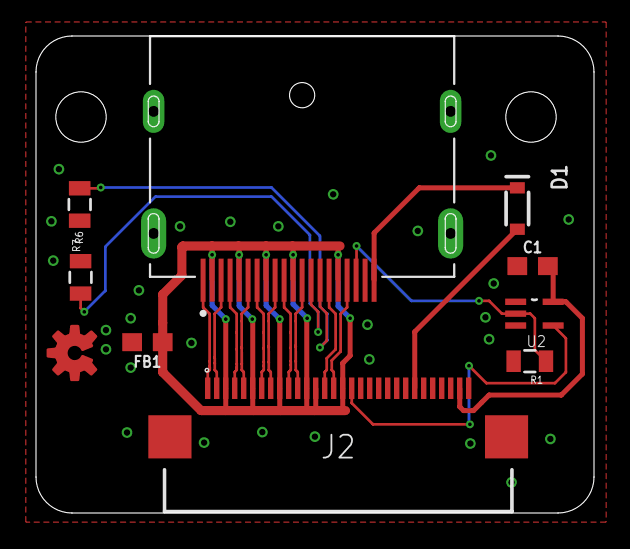
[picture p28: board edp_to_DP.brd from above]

Board: 4 copper layers, 31.0 x 26.5 mm, 10 parts (0 on the bottom side), 20 nets.

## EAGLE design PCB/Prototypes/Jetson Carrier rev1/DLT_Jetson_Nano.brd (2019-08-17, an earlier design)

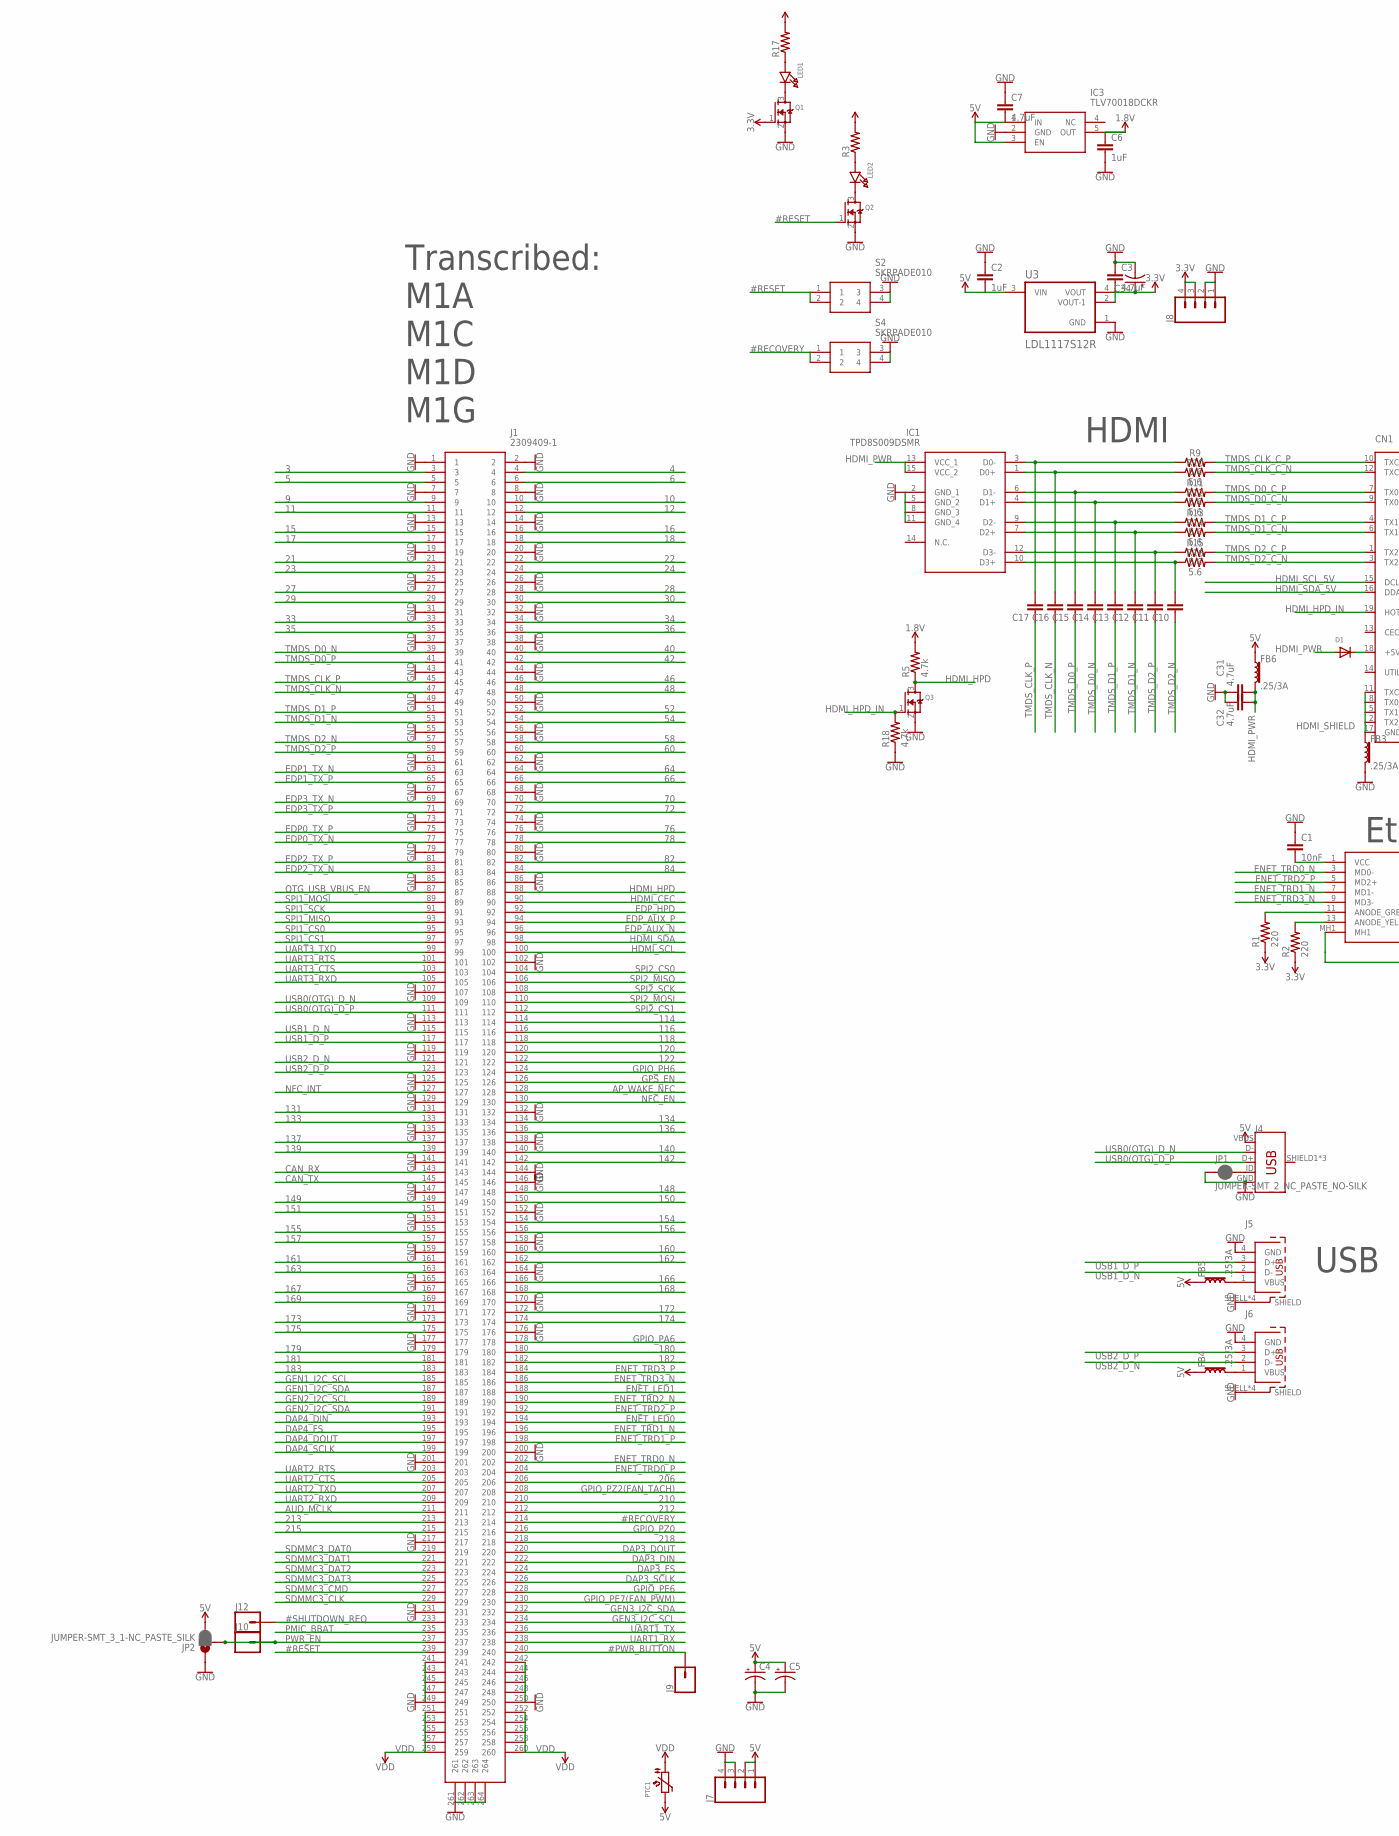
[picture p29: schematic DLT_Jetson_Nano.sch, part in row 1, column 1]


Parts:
C1: 10nF; 0603
C2, C6: 1uF; 0603
C3, C7, C29, C30, C31, C32: 4.7uF; 0603
C4, C5, C34: CAP_POLD; PANASONIC_D
C8, C9, C26, C33, C35: 0.1uF; 0603
C10, C11, C12, C13, C14, C15, C16, C17, C18, C19, C20, C21, C22, C23, C24, C25, C27, C28: 0.1uF; 0402
CN1: HDMI_MOLEX_47151-0001
D1, D2: DIODESMA; SMADIODE
FB1, FB2, FB3, FB4, FB5, FB6, FB7: .25/3A; 0603
IC1, IC2: TPD8S009DSMR
IC3: TLV70018DCKR; SOT65P210X110-5N
J1: 2309409-1
J2: 47272-0001; MOLEX_47272-0001
J3: 93626-3508; 936263508
J4: USB_MICRO-B_FEMALE-SMT; USB-B-MICRO-SMD
J5, J6: 629104190121
J7, J8: CONN_04LOCK_LONGPADS; 1X04_LOCK_LONGPADS
J9, J10, J12: CONN_01; 1X01
J11: CONN_06SILK_FEMALE_PTH; 1X06
J13: CONN_03; 1X03
J14: CONN_04; 1X04
JP1: JUMPER-SMT_2_NC_PASTE_NO-SILK; SMT-JUMPER_2_NC_PASTE_NO-SILK
JP2: JUMPER-SMT_3_1-NC_PASTE_SILK; SMT-JUMPER_3_1-NC_PASTE_SILK
LED1, LED2: LED0805; CHIPLED_0805
PTC1: PTC1206; 1206
Q1, Q2, Q3: MOSFET-NWAVE; SOT23-W
R1, R2: 220; 0805
R3, R17: RESISTOR0805-RES; 0805
R4, R6, R7, R8: 10k; 0805
R5, R18: 4.7k; 0805
R9, R10, R11, R12, R13, R14, R15, R16: 5.6; 0402
R19, R20, R21: 100k; 0805
R22, R23: 1M; 0805
S2, S4: SKRPADE010
U1: SN74LV1T125DCKR; SOT65P210X110-5N
U2: PCA9517AD,118; SOIC127P600X175-8N
U3: LDL1117S12R; SOT230P700X180-4N
U4: TXS0108EPWR-TSSOP20; TSSOP20-0.65-6.5X4.4MM

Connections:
1.8V: C6.1, C26.2, C33.2, IC3.5 (OUT), R5.2, U1.5 (VCC), U4.2 (VCCA), U4.10 (OE)
3: J1.3
3.3V: C3.2, C9.2, C34.+, C35.1, FB7.1, J8.3, J8.4, J11.1, J14.1, Q1.1 (G), R1.1, R2.1, R4.1, R6.1, U2.1 (VCC(A)), U3.2 (VOUT-1), U3.4 (VOUT), U4.19 (VCCB)
4: J1.4
5: J1.5
5V: C2.2, C4.+, C5.+, C7.2, FB4.1, FB5.1, FB6.1, IC2.13 (VCC_1), IC2.15 (VCC_2), IC3.1 (IN), IC3.3 (EN), J4.VBUS, J7.1, J7.2, JP2.3, PTC1.2, R3.2, R17.2, U3.3 (VIN)
6: J1.6
9: J1.9
10: J1.10
11: J1.11
12: J1.12
15: J1.15
16: J1.16
17: J1.17
18: J1.18
21: J1.21
22: J1.22
23: J1.23
24: J1.24
27: J1.27
28: J1.28
29: J1.29
30: J1.30
33: J1.33
34: J1.34
35: J1.35
36: J1.36
40: J1.40
42: J1.42
46: J1.46
48: J1.48
52: J1.52
54: J1.54
58: J1.58
60: J1.60
64: J1.64
66: J1.66
70: J1.70
72: J1.72
76: J1.76
78: J1.78
82: J1.82
84: J1.84
114: J1.114
116: J1.116
118: J1.118
120: J1.120
122: J1.122
131: J1.131
133: J1.133
134: J1.134
136: J1.136
137: J1.137
139: J1.139
140: J1.140
142: J1.142
148: J1.148
149: J1.149
150: J1.150
151: J1.151
154: J1.154
155: J1.155
156: J1.156
157: J1.157
160: J1.160
161: J1.161
162: J1.162
163: J1.163
166: J1.166
167: J1.167
168: J1.168
169: J1.169
172: J1.172
173: J1.173
174: J1.174
175: J1.175
179: J1.179
180: J1.180
181: J1.181
182: J1.182
183: J1.183
206: J1.206
210: J1.210
212: J1.212
213: J1.213
215: J1.215
218: J1.218
#PWR_BUTTON: J1.240, J9.1
#RECOVERY: J1.214, S4.1, S4.2
#RESET: J1.239, Q2.1 (G), S2.1, S2.2
#SHUTDOWN_REQ: J1.233, J12.1
AP_WAKE_NFC: J1.128
AUD_MCLK: J1.211, U4.7 (A6)
AUD_MCLK_3V: J11.5, U4.14 (B6)
CAN_RX: J1.143
CAN_TX: J1.145
CONFIG1: J2.13 (CONFIG1), R22.2
CONFIG2: J2.14 (CONFIG2), R23.2
DAP3_DIN: J1.222
DAP3_DOUT: J1.220
DAP3_FS: J1.224
DAP3_SCLK: J1.226
DAP4_DIN: J1.193
DAP4_DOUT: J1.197, U4.5 (A4)
DAP4_DOUT_3V: J11.3, U4.16 (B4)
DAP4_FS: J1.195, U4.4 (A3)
DAP4_FS_3V: J11.2, U4.17 (B3)
DAP4_SCLK: J1.199, U4.6 (A5)
DAP4_SCLK_3V: J11.4, U4.15 (B5)
DP_GND: FB2.1, J2.2 (TX0_GND), J2.5 (TX1_GND), J2.8 (TX2_GND), J2.11 (TX3_GND), J2.16 (AUX_GND)
DP_HPD_IN: J2.18 (HPD), R19.1, U1.2 (A)
DP_PWR: C29.2, C30.2, D2.A, FB7.2, R21.2
EDP0_TX_C_N: C25.2, IC2.10 (D3+), J2.3 (TX0_N)
EDP0_TX_C_P: C24.2, IC2.12 (D3-), J2.1 (TX0_P)
EDP0_TX_N: C25.1, J1.77
EDP0_TX_P: C24.1, J1.75
EDP1_TX_C_N: C23.2, IC2.7 (D2+), J2.6 (TX1_N)
EDP1_TX_C_P: C22.2, IC2.9 (D2-), J2.4 (TX1_P)
EDP1_TX_N: C23.1, J1.63
EDP1_TX_P: C22.1, J1.65
EDP2_TX_C_N: C21.2, IC2.4 (D1+), J2.9 (TX2_N)
EDP2_TX_C_P: C20.2, IC2.6 (D1-), J2.7 (TX2_P)
EDP2_TX_N: C21.1, J1.83
EDP2_TX_P: C20.1, J1.81
EDP3_TX_C_N: C19.2, IC2.1 (D0+), J2.12 (TX3_N)
EDP3_TX_C_P: C18.2, IC2.3 (D0-), J2.10 (TX3_P)
EDP3_TX_N: C19.1, J1.69
EDP3_TX_P: C18.1, J1.71
EDP_AUX_C_N: C28.1, J2.17 (AUX_CH_N), R21.1
EDP_AUX_C_P: C27.1, J2.15 (AUX_CH_P), R20.1
EDP_AUX_N: C28.2, J1.96
EDP_AUX_P: C27.2, J1.94
EDP_HPD: J1.92, U1.4 (Y)
ENET_LED0: J1.194, J3.14 (CATHODE_YELLOW)
ENET_LED1: J1.188, J3.12 (CATHODE_GREEN)
ENET_TRD0_N: J1.202, J3.3 (MD0-)
ENET_TRD0_P: J1.204, J3.2 (MD0+)
ENET_TRD1_N: J1.196, J3.7 (MD1-)
ENET_TRD1_P: J1.198, J3.4 (MD1+)
ENET_TRD2_N: J1.190, J3.6 (MD2-)
ENET_TRD2_P: J1.192, J3.5 (MD2+)
ENET_TRD3_N: J1.186, J3.9 (MD3-)
ENET_TRD3_P: J1.184, J3.8 (MD3+)
GEN1_I2C_SCL: J1.185
GEN1_I2C_SDA: J1.187
GEN2_I2C_SCL: J1.189
GEN2_I2C_SDA: J1.191
GEN3_I2C_SCL: J1.234, U4.9 (A8)
GEN3_I2C_SCL_3V: J14.4, U4.12 (B8)
GEN3_I2C_SDA: J1.232, U4.8 (A7)
GEN3_I2C_SDA_3V: J14.3, U4.13 (B7)
GND: C1.1, C2.1, C3.1, C4.-, C5.-, C6.2, C7.1, C8.2, C9.1, C26.1, C29.1, C30.1, C31.1, C32.1, C33.1, C34.-, C35.2, CN1.P$1 (GND), CN1.P$2 (GND), CN1.P$3 (GND), CN1.P$4 (GND), FB1.2, FB2.2, FB3.2, IC1.2 (GND_1), IC1.5 (GND_2), IC1.8 (GND_3), IC1.11 (GND_4), IC2.2 (GND_1), IC2.5 (GND_2), IC2.8 (GND_3), IC2.11 (GND_4), IC3.2 (GND), J1.1, J1.2, J1.7, J1.8, J1.13, J1.14, J1.19, J1.20, J1.25, J1.26, J1.31, J1.32, J1.37, J1.38, J1.43, J1.44, J1.49, J1.50, J1.55, J1.56, J1.61, J1.62, J1.67, J1.68, J1.73, J1.74, J1.79, J1.80, J1.85, J1.86, J1.102, J1.107, J1.113, J1.119, J1.125, J1.129, J1.132, J1.135, J1.138, J1.141, J1.144, J1.146, J1.147, J1.152, J1.153, J1.158, J1.159, J1.164, J1.165, J1.170, J1.171, J1.176, J1.177, J1.200, J1.201, J1.217, J1.231, J1.241, J1.242, J1.243, J1.244, J1.245, J1.246, J1.247, J1.248, J1.249, J1.250, J1.261, J1.262, J1.263, J1.264, J2.19 (RETURN), J2.S1 (SHIELD), J2.S2 (SHIELD), J2.S3 (SHIELD), J2.S4 (SHIELD), J3.10 (GND), J4.GND, J5.4 (GND), J5.SHELL (SHIELD), J5.SHELL1 (SHIELD), J5.SHELL2 (SHIELD), J5.SHELL3 (SHIELD), J6.4 (GND), J6.SHELL (SHIELD), J6.SHELL1 (SHIELD), J6.SHELL2 (SHIELD), J6.SHELL3 (SHIELD), J7.3, J7.4, J8.1, J8.2, J11.6, J13.1, J14.2, JP1.1, JP2.1, Q1.2 (S), Q2.2 (S), Q3.2 (S), R18.1, R19.2, R20.2, R22.1, R23.1, S2.3, S2.4, S4.3, S4.4, U1.1 (#OE), U1.3 (GND), U2.4 (GND), U3.1 (GND), U4.11 (GND)
GPIO_PA6: J1.178
GPIO_PE6: J1.228
GPIO_PE7(FAN_PWM): J1.230
GPIO_PH6: J1.124
GPIO_PZ0: J1.216
GPIO_PZ2(FAN_TACH): J1.208
GPS_EN: J1.126
HDMI_5V_DIODE: CN1.18 (+5V), D1.C
HDMI_CEC: J1.90
HDMI_HPD: J1.88, Q3.3 (D), R5.1
HDMI_HPD_IN: CN1.19 (HOTPLUG), Q3.1 (G), R18.2
HDMI_PWR: C8.1, C31.2, C32.2, D1.A, FB6.2, IC1.13 (VCC_1), IC1.15 (VCC_2), R7.2, R8.2, U2.8 (VCC(B))
HDMI_SCL: J1.100, R4.2, U2.2 (SCLA)
HDMI_SCL_5V: CN1.15 (DCLK), R8.1, U2.7 (SCLB)
HDMI_SDA: J1.98, R6.2, U2.3 (SDAA)
HDMI_SDA_5V: CN1.16 (DDAT), R7.1, U2.6 (SDAB)
HDMI_SHIELD: CN1.2 (TX2_SHIELD), CN1.5 (TX1_SHIELD), CN1.8 (TX0_SHIELD), CN1.11 (TXC_SHIELD), CN1.17 (GND), FB3.1
unnamed: J3.11 (ANODE_GREEN), R1.2
unnamed: J3.13 (ANODE_YELLOW), R2.2
unnamed: C1.2, J3.1 (VCC)
unnamed: FB1.1, J3.MH1, J3.MH2
unnamed: LED2.C, Q2.3 (D)
unnamed: FB5.2, J5.1 (VBUS)
unnamed: FB4.2, J6.1 (VBUS)
unnamed: LED2.A, R3.1
unnamed: J4.ID, JP1.2
unnamed: LED1.C, Q1.3 (D)
unnamed: LED1.A, R17.1
unnamed: D2.C, J2.20 (PWR)
NFC_EN: J1.130
NFC_INT: J1.127
OTG_USB_VBUS_EN: J1.87
PMIC_BBAT: J1.235
PWR_EN: J1.237, J10.1, JP2.2
SDMMC3_CLK: J1.229
SDMMC3_CMD: J1.227
SDMMC3_DAT0: J1.219
SDMMC3_DAT1: J1.221
SDMMC3_DAT2: J1.223
SDMMC3_DAT3: J1.225
SPI1_CS0: J1.95
SPI1_CS1: J1.97
SPI1_MISO: J1.93
SPI1_MOSI: J1.89
SPI1_SCK: J1.91
SPI2_CS0: J1.104
SPI2_CS1: J1.112
SPI2_MISO: J1.106
SPI2_MOSI: J1.110
SPI2_SCK: J1.108
TMDS_CLK_C1_N: C16.2, IC1.1 (D0+), R10.1
TMDS_CLK_C1_P: C17.2, IC1.3 (D0-), R9.1
TMDS_CLK_C_N: CN1.12 (TXC-), R10.2
TMDS_CLK_C_P: CN1.10 (TXC+), R9.2
TMDS_CLK_N: C16.1, J1.47
TMDS_CLK_P: C17.1, J1.45
TMDS_D0_C1_N: C14.2, IC1.4 (D1+), R12.1
TMDS_D0_C1_P: C15.2, IC1.6 (D1-), R11.1
TMDS_D0_C_N: CN1.9 (TX0-), R12.2
TMDS_D0_C_P: CN1.7 (TX0+), R11.2
TMDS_D0_N: C14.1, J1.39
TMDS_D0_P: C15.1, J1.41
TMDS_D1_C1_N: C12.2, IC1.7 (D2+), R14.1
TMDS_D1_C1_P: C13.2, IC1.9 (D2-), R13.1
TMDS_D1_C_N: CN1.6 (TX1-), R14.2
TMDS_D1_C_P: CN1.4 (TX1+), R13.2
TMDS_D1_N: C12.1, J1.53
TMDS_D1_P: C13.1, J1.51
TMDS_D2_C1_N: C10.2, IC1.10 (D3+), R16.1
TMDS_D2_C1_P: C11.2, IC1.12 (D3-), R15.1
TMDS_D2_C_N: CN1.3 (TX2-), R16.2
TMDS_D2_C_P: CN1.1 (TX2+), R15.2
TMDS_D2_N: C10.1, J1.57
TMDS_D2_P: C11.1, J1.59
UART1_RX: J1.238, U4.3 (A2)
UART1_RX_3V: J13.3, U4.18 (B2)
UART1_TX: J1.236, U4.1 (A1)
UART1_TX_3V: J13.2, U4.20 (B1)
UART2_CTS: J1.205
UART2_RTS: J1.203
UART2_RXD: J1.209
UART2_TXD: J1.207
UART3_CTS: J1.103
UART3_RTS: J1.101
UART3_RXD: J1.105
UART3_TXD: J1.99
USB0(OTG)_D_N: J1.109, J4.D-
USB0(OTG)_D_P: J1.111, J4.D+
USB1_D_N: J1.115, J5.2 (D-)
USB1_D_P: J1.117, J5.3 (D+)
USB2_D_N: J1.121, J6.2 (D-)
USB2_D_P: J1.123, J6.3 (D+)
VDD: J1.251, J1.252, J1.253, J1.254, J1.255, J1.256, J1.257, J1.258, J1.259, J1.260, PTC1.1

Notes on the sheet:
Transcribed: M1A M1C M1D M1G
DisplayPort
HDMI
Ethernet
GPIO/I2S
USB


Board: 4 copper layers, 111.0 x 100.0 mm, 99 parts (0 on the bottom side), 113 nets.

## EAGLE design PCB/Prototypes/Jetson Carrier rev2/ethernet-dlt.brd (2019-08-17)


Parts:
C2: 10nF; 0603
FB2: .25/3A; 0603
J1: 505110-2091; 5051102091
J2: 93626-3508; 936263508
LOGO1: OSHW-LOGOS-COPPER; OSHW-LOGO-S_COPPER
R3, R4: 220; 0805

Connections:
3.3V: J1.19, R3.1, R4.1
5V: J1.20
ENET_LED0: J1.3, J2.14 (CATHODE_YELLOW)
ENET_LED1: J1.2, J2.12 (CATHODE_GREEN)
ENET_TRD0_N: J1.14, J2.3 (MD0-)
ENET_TRD0_P: J1.15, J2.2 (MD0+)
ENET_TRD1_N: J1.11, J2.7 (MD1-)
ENET_TRD1_P: J1.12, J2.4 (MD1+)
ENET_TRD2_N: J1.8, J2.6 (MD2-)
ENET_TRD2_P: J1.9, J2.5 (MD2+)
ENET_TRD3_N: J1.6, J2.9 (MD3-)
ENET_TRD3_P: J1.5, J2.8 (MD3+)
GND: C2.1, FB2.2, J1.4, J1.7, J1.10, J1.13, J1.16, J1.MP1, J1.MP2, J2.10 (GND)
unnamed: J2.11 (ANODE_GREEN), R3.2
unnamed: J2.13 (ANODE_YELLOW), R4.2
unnamed: C2.2, J2.1 (VCC)
unnamed: FB2.1, J2.MH1, J2.MH2


Board: 4 copper layers, 31.0 x 32.0 mm, 7 parts (0 on the bottom side), 16 nets.

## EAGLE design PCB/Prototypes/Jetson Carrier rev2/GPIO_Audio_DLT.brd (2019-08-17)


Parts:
C1, C2: 0.1uF; 0603
J1: 505110-2091; 5051102091
J2: CONN_10X2; 2X10
LOGO1: OSHW-LOGOS-COPPER; OSHW-LOGO-S_COPPER
U1: TXS0108EPWR-TSSOP20; TSSOP20-0.65-6.5X4.4MM

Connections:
1.8V: C1.2, J1.16, J2.16, U1.2 (VCCA), U1.10 (OE)
3.3V: C2.1, J1.15, J2.18, U1.19 (VCCB)
5V: J1.13, J1.14, J2.20
AUD_MCLK: J1.10, J2.14, U1.7 (A6)
AUD_MCLK_3V: J2.13, U1.14 (B6)
DAP4_DOUT: J1.8, J2.10, U1.5 (A4)
DAP4_DOUT_3V: J2.9, U1.16 (B4)
DAP4_FS: J1.7, J2.8, U1.4 (A3)
DAP4_FS_3V: J2.7, U1.17 (B3)
DAP4_SCLK: J1.9, J2.12, U1.6 (A5)
DAP4_SCLK_3V: J2.11, U1.15 (B5)
GEN3_I2C_SCL: J1.12, U1.9 (A8)
GEN3_I2C_SCL_3V: J2.17, U1.12 (B8)
GEN3_I2C_SDA: J1.11, U1.8 (A7)
GEN3_I2C_SDA_3V: J2.15, U1.13 (B7)
GND: C1.1, C2.2, J1.1, J1.2, J1.17, J1.18, J1.19, J1.20, J1.MP1, J1.MP2, J2.1, J2.2, J2.19, U1.11 (GND)
UART1_RX: J1.6, U1.3 (A2)
UART1_RX_3V: J2.5, U1.18 (B2)
UART1_TX: J1.5, U1.1 (A1)
UART1_TX_3V: J2.3, U1.20 (B1)
UART3_RXD: J1.4, J2.6
UART3_TXD: J1.3, J2.4


Board: 2 copper layers, 34.0 x 23.0 mm, 6 parts (0 on the bottom side), 22 nets.

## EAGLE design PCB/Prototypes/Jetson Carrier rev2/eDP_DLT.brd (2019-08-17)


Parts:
C1: 0.1uF; 0603
C2, C5: 4.7uF; 0603
C3, C4: 1.0uF; 0603
D2: 3A/40V/500mV; SMA-DIODE
J1, J2: 54132-3062
JP1: JUMPER-SMT_2_NO_NO-SILK; SMT-JUMPER_2_NO_NO-SILK
JP2, JP3, JP4: JUMPER-SMT_3_1-NC_PASTE_NO-SILK; SMT-JUMPER_3_1-NC_PASTE_NO-SILK
L2: SRP5020TA-4R7M; IND_SRP5020TA-4R7M
R1: 100k; 0603-RES
R2, R3: 10k; 0603-RES
TP1, TP2, TP3, TP4, TP5, TP6, TP7, TP8: TEST-POINT3; PAD.03X.03
TPS6117: TPS61177ARGRR; RGR0020A
U2: SN74LV1T125DCKR; SOT65P210X110-5N
U$2: FB; 0603

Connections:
1.8V: C1.2, J1.29, JP1.1, JP4.1, R2.2, R3.1, U2.5 (VCC)
5V: C2.1, C3.1, J1.21, J1.27, L2.1, TPS6117.18 (VINB)
BL_EN: JP4.2, TPS6117.19 (ENB)
BL_PWM: JP2.2, TPS6117.20 (PWMB)
DP_GND: J1.3, J1.6, J1.9, J1.12, J1.13, J1.16, J2.2, J2.5, J2.8, J2.11, U$2.1
DP_HPD_IN: J2.17, R1.1, U2.2 (A)
DP_PWR_3V3: J1.24, J2.12, J2.13, TP7.P$1
EDP0_TX_C_N: J1.2, J2.6
EDP0_TX_C_P: J1.1, J2.7
EDP1_TX_C_N: J1.5, J2.3
EDP1_TX_C_P: J1.4, J2.4
EDP2_TX_C_N: J1.8
EDP2_TX_C_P: J1.7
EDP3_TX_C_N: J1.11
EDP3_TX_C_P: J1.10
EDP_AUX_N: J1.15, J2.10
EDP_AUX_P: J1.14, J2.9
EDP_HPD: J1.17, U2.4 (Y)
FB1: J2.27, TP1.P$1, TPS6117.12 (CS1)
FB2: J2.26, TP2.P$1, TPS6117.11 (CS2)
FB3: J2.25, TP3.P$1, TPS6117.10 (CS3)
FB4: J2.24, TP4.P$1, TPS6117.8 (CS4)
FB5: J2.23, TP5.P$1, TPS6117.7 (CS5)
GEN2_I2C_SCL: J1.23, R3.2, TPS6117.2 (SCL)
GEN2_I2C_SDA: J1.22, R2.1, TPS6117.1 (SDA)
GND: C1.1, C2.2, C3.2, C4.2, C5.2, J1.18, J1.19, J1.20, J1.25, J1.31, J1.32, J2.15, J2.16, J2.31, J2.32, R1.2, TPS6117.5 (AGND), TPS6117.6 (CS6), TPS6117.9 (AGND_2), TPS6117.15 (PGND), TPS6117.21 (PAD), U2.1 (#OE), U2.3 (GND), U$2.2
GPIO13_PE6_PWM: J1.28, JP3.3
LCD_BL_EN: J1.26, JP4.3
LCD_BL_PWM: J1.30, JP2.3, JP3.1
LXB: D2.A, L2.2, TPS6117.16 (LXB), TPS6117.17 (LXB_2)
unnamed: JP1.2, TPS6117.3 (VCC)
unnamed: C4.1, TPS6117.4 (REF)
PWMI: J2.18, JP3.2
PWMO: J2.19, JP2.1, TP8.P$1
VLED: C5.1, D2.C, J2.29, J2.30, TP6.P$1, TPS6117.14 (VLED)


Board: 4 copper layers, 34.0 x 26.0 mm, 27 parts (0 on the bottom side), 31 nets.

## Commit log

2019-09-30 added mechanical files
    [Back Plate.stl, Corner Bottom Left.stl, Corner Bottom Right.stl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]
2019-10-01 clean up of rev.2 PCB files
    [DLT_Jetson_Nano_BOM.csv, DP_eDP_10inch.brd, eDP_DLT_10inch.brd]

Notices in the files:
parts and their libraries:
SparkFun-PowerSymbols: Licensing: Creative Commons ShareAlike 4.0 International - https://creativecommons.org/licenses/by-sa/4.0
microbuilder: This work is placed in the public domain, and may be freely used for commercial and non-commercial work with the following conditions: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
